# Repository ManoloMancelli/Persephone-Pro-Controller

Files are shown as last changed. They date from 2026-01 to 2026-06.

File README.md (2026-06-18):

# Persephone Pro Controller
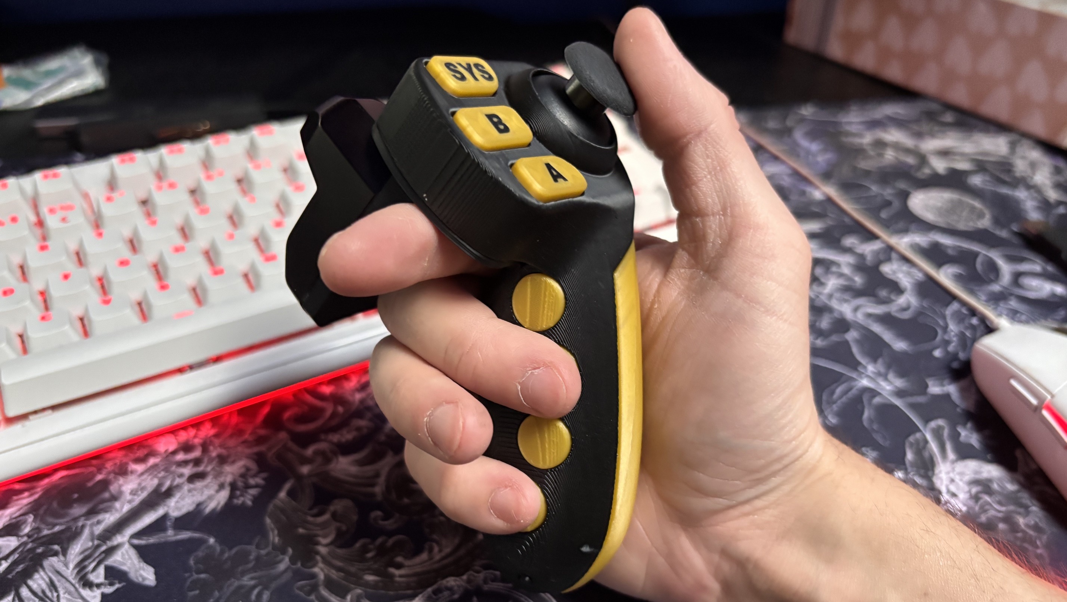
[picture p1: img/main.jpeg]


Persephone Pro controller is a DiY, "knuckle"-like controller for SteamVR

It uses a 3D printed shell and custom electronics based on Arduino along with Vive Tracker for full 6DoF tracking

The controller uses the excellent [HadesVR](https://github.com/HadesVR/HadesVR) Firmware

## V1 - "Clamp" (Finished)

### Known Issues:
- Tracker is oriented in wrong position under SteamVR (Don't know how to fix it yet!)

If orientation is important to you and you can't use it as is, wait for the version 1.1

#

Version 1.0 is meant to function as a "testing rig" for the project.

It's not meant to look pretty and some of the parts may feel uncomfortable.

It's a simple build that will show you how everything works and it's designed to use as cheap parts as possible so if it turns out it's not for you then you won't feel any guilt about it.

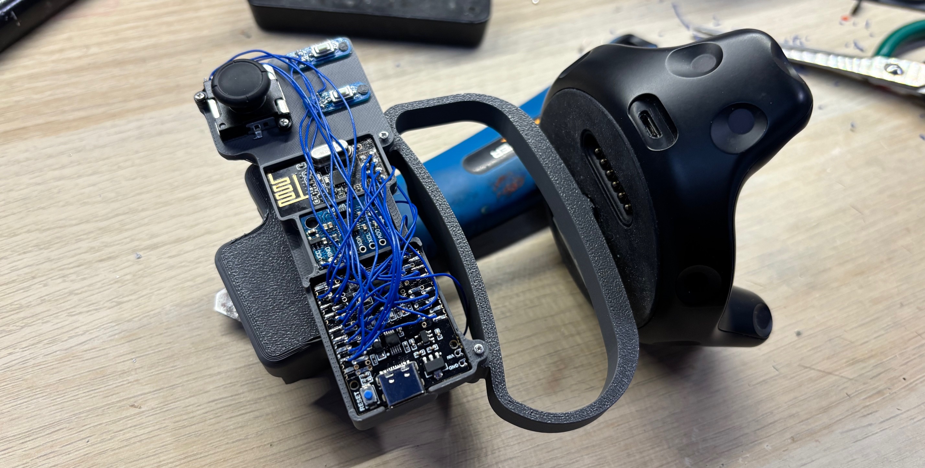
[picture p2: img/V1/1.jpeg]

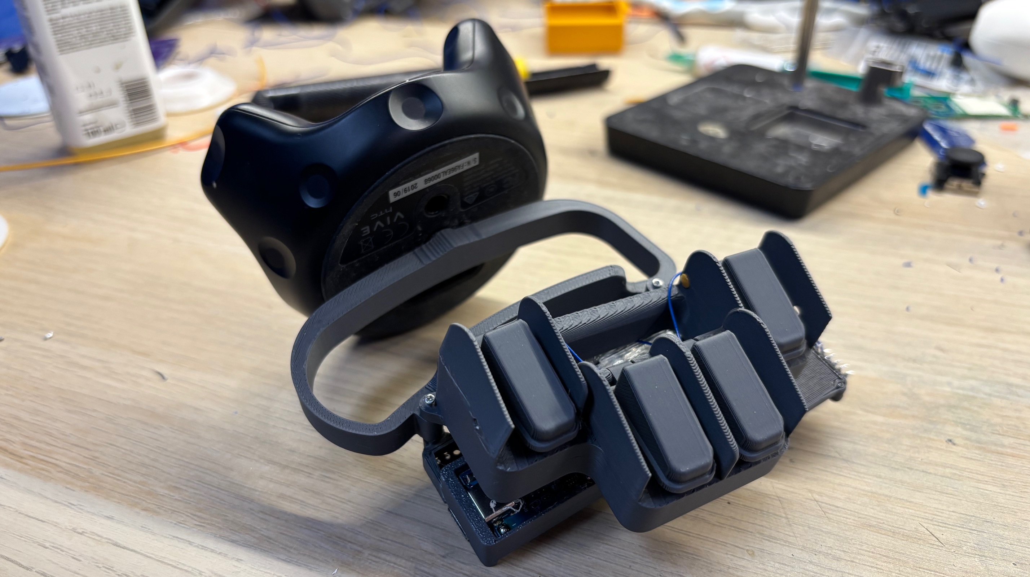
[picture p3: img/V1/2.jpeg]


- #### [Changelog](/Changelog/V1/V1.md)
- #### [Firmware](/Software/Firmware/V1/)
- #### [BOM](/Hardware/V1/BOM.md)
- #### [STL Files](/Hardware/V1/STL)
- #### [CAD Files]()
- #### [Tutorial](/Docs/V1/Tutorial.md)

## V2.0 - "Gas Pump" (Finished)

A Full redesign

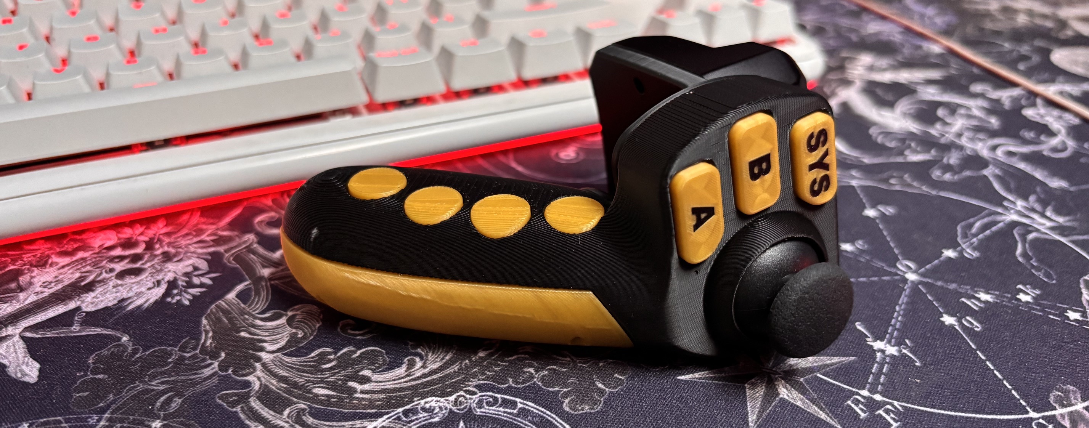
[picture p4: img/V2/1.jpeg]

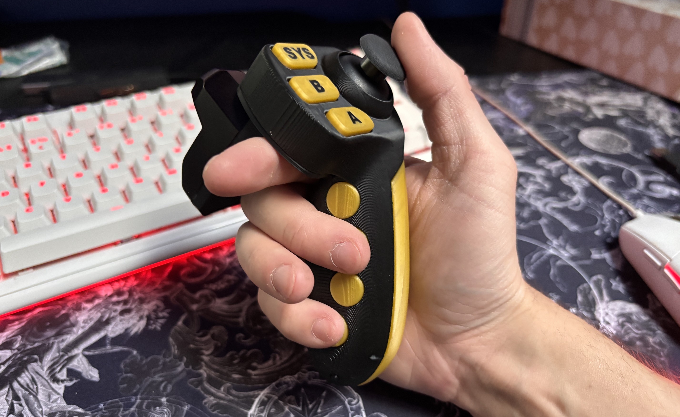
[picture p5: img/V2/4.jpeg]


- #### [Firmware]()
- #### [CAD Files](https://www.patreon.com/Manollo/posts/persephone-pro-0-161451840/)
- #### [STL Files](https://www.patreon.com/Manollo/posts/persephone-pro-0-161452585/)
- #### [HadesVR Index Controller Development Board]()
- #### [Charger Board]()

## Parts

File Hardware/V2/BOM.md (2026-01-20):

# Persephone Pro Controller V2 BOM

Below is a full list of parts and tools required for the V2 version.

Quantities provided are for a single controller

### Components

#### - [10k Potentiometer](https://aliexpress.com/item/1005004816793978.html) - 5 Pcs
#### - [ESP-WROOM-32](https://aliexpress.com/item/1005009709643094.html) - 1 Pcs
#### - Thin wire
#### - 3D printed parts

### Tools

#### - Soldering Iron

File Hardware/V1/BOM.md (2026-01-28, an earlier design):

# Persephone Pro Controller V1 BOM

A full Bill of Materials for the V1 version of Persephone Pro Controller

Below list of parts is for a single controller

- #### [Arduino Uno Mini - 1pcs](http://aliexpress.com/item/1005009656475222.html)
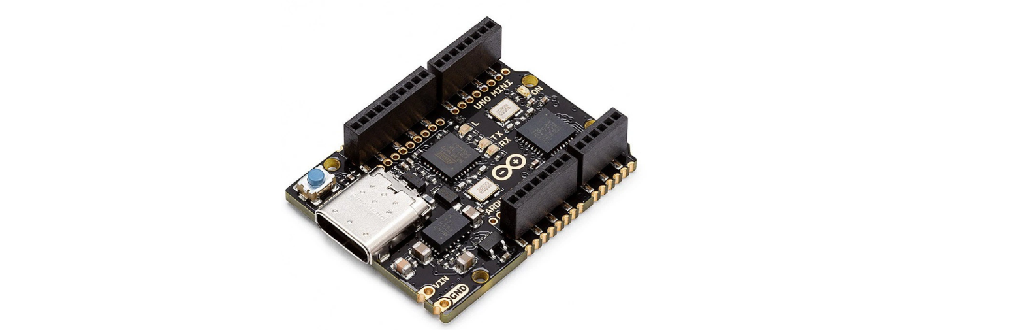
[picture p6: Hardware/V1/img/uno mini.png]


- #### [NRF24L01 - 1pcs](http://aliexpress.com/item/1005001580632657.html)
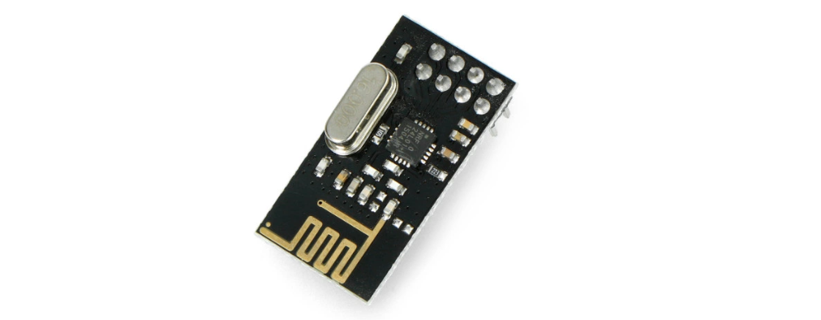
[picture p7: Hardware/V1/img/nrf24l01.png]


- #### [MPU6500 - 1pcs](http://aliexpress.com/item/1005009877371293.html)
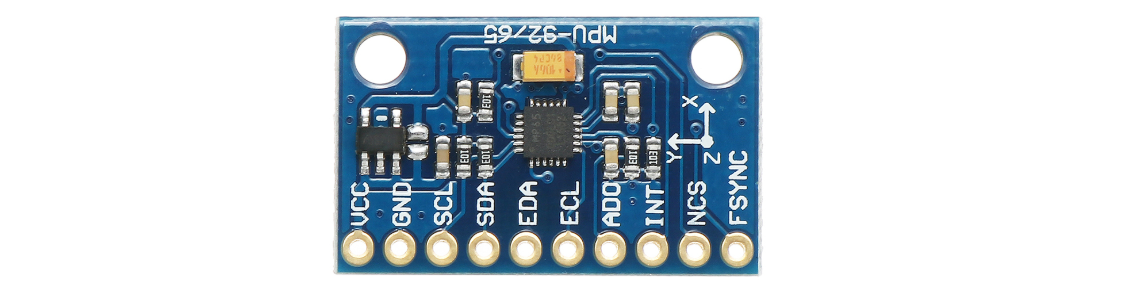
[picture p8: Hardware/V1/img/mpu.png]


- #### [TP4056 - 1pcs](http://aliexpress.com/item/1005009519806288.html)
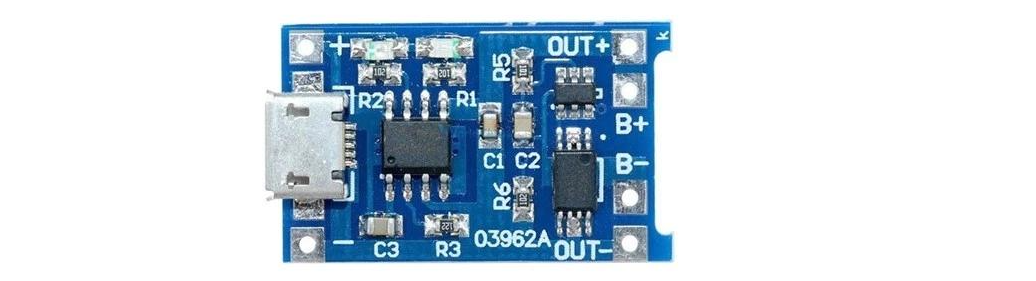
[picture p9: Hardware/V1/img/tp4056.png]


- #### [Battery 3.7V 20x30mm - 1pcs](http://aliexpress.com/item/1005003495504020.html)
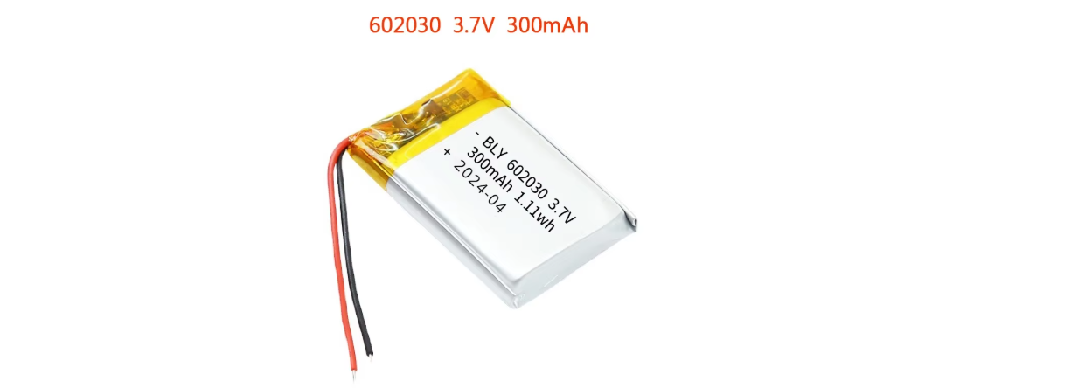
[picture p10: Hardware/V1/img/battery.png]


- #### [Joystick - 1pcs](http://aliexpress.com/item/1005006007198466.html)
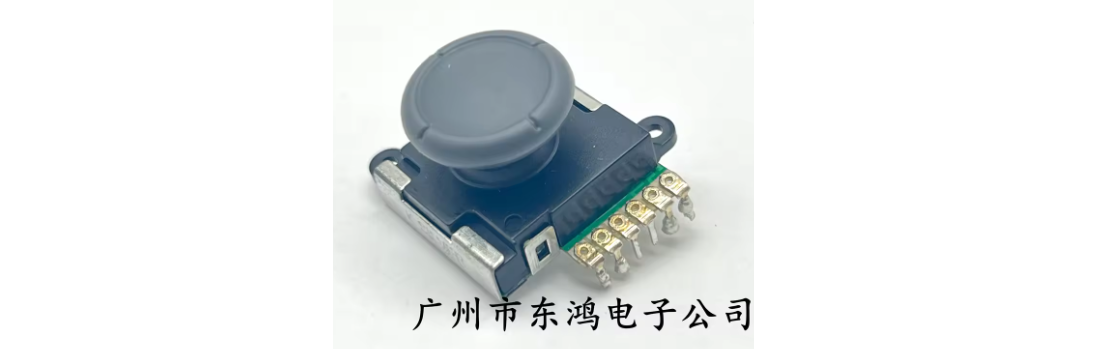
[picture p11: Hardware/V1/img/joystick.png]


- #### [Buttons - 6pcs](http://aliexpress.com/item/1005001836287232.html)
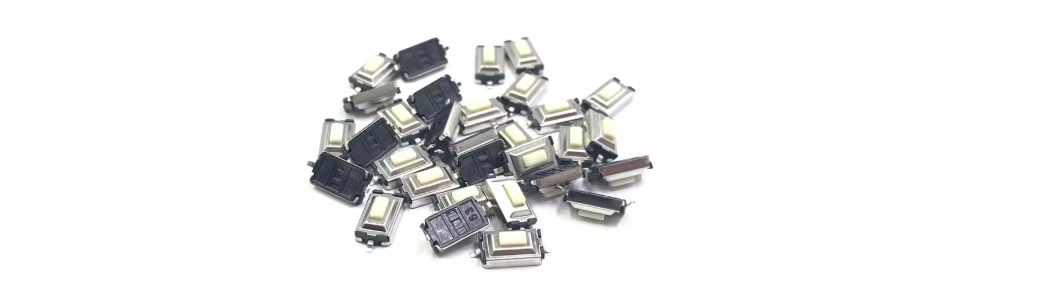
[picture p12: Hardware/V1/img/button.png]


- #### [Button PCB - 6pcs](/Hardware/V1/Electronics/Button%20PCB/Button%20PCB.zip)
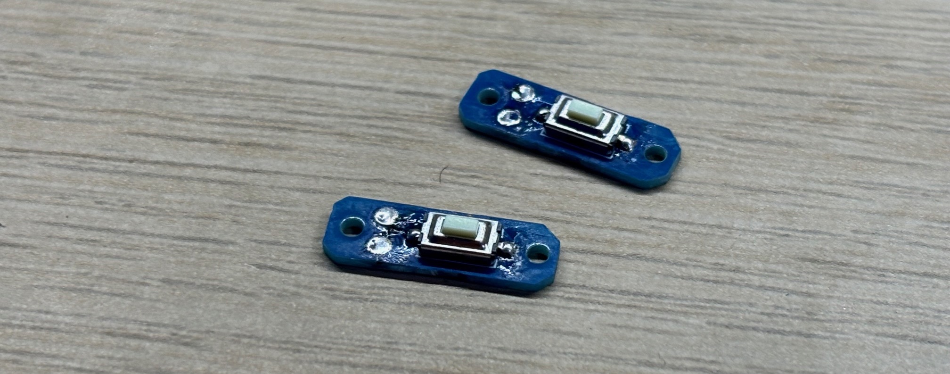
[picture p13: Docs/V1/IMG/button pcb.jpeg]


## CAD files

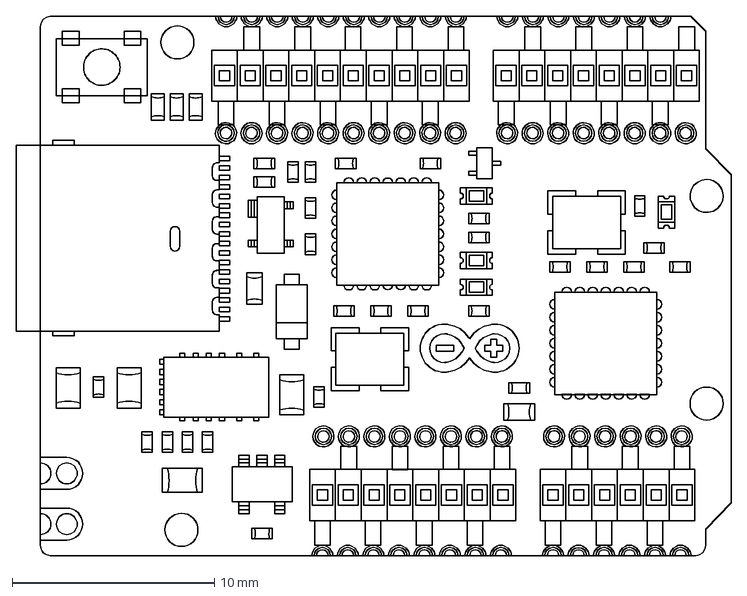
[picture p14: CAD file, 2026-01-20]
Hardware/Arduino Uno Mini.dxf
35.4 x 26.7 mm

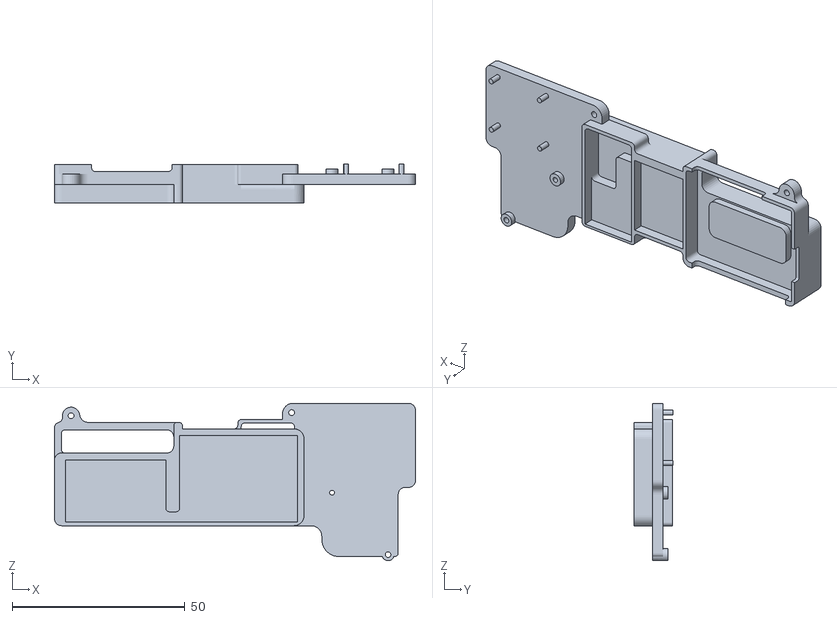
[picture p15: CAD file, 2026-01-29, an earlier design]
Hardware/V1/STL/Main Frame.stl
104.4 x 11.4 x 45.5

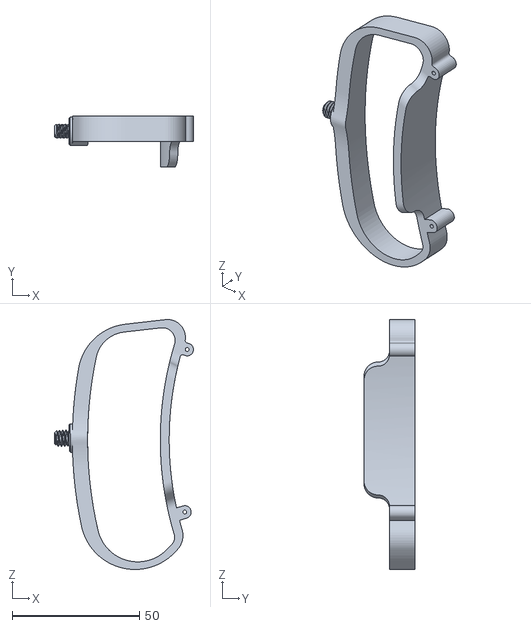
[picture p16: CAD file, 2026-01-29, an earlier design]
Hardware/V1/STL/Bumper.stl
54.6 x 20.0 x 98.1

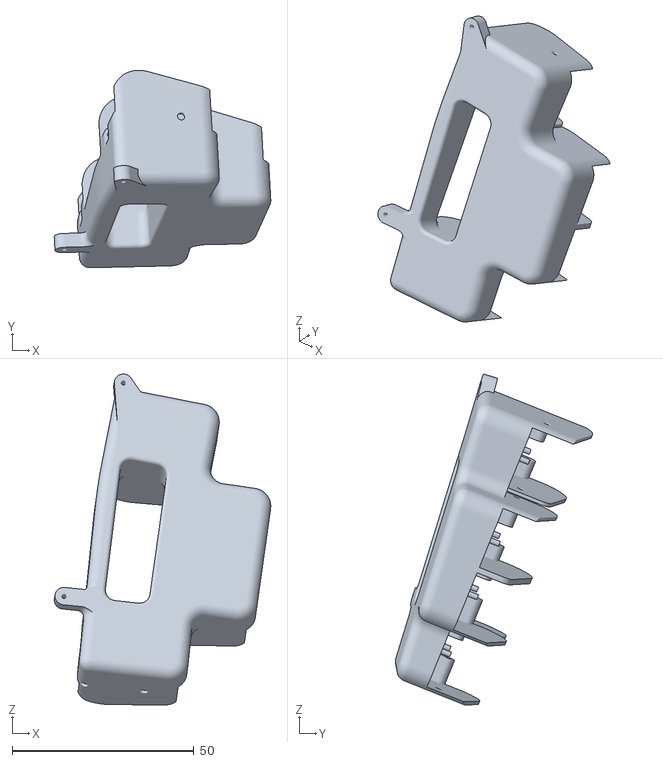
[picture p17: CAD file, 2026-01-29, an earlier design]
Hardware/V1/STL/Finger Array.stl
59.6 x 54.4 x 91.1

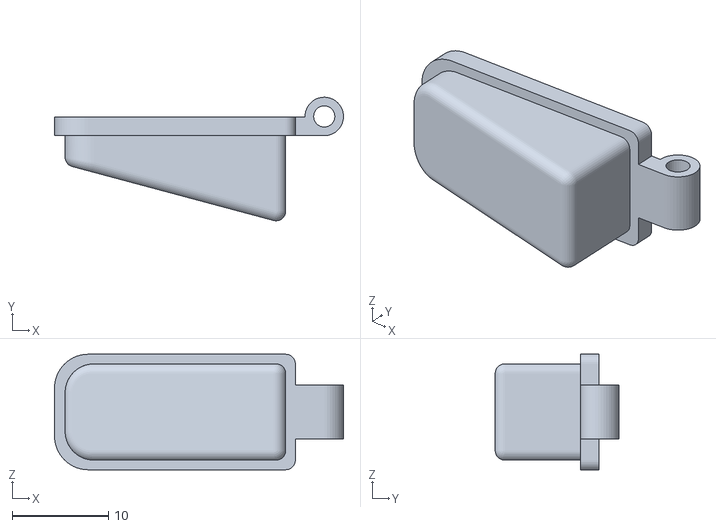
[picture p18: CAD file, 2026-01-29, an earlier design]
Hardware/V1/STL/Finger Button.stl
30.0 x 12.8 x 12.0

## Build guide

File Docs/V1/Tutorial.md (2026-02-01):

# Persephone Pro Controller V1 Assembly Guide

#
## This tutorial assumes that you already have a working HadesVR headset
#

## Required Parts and Tools

#### - All of the electronic parts included in the [BOM File](/Hardware/V1/BOM.md)
#### - Soldering Iron with fine tip
#### - Phillips Screwdriver
#### - Thin wire (I use Kynar)
#### - Double sided tape (Basic type. Nothing fancy)
#### - [3D printed parts](/Hardware/V1/STL)

## Main Frame Assembly

- ### 3D print the [Main Frame](/Hardware/V1/STL/Main%20Frame.stl)
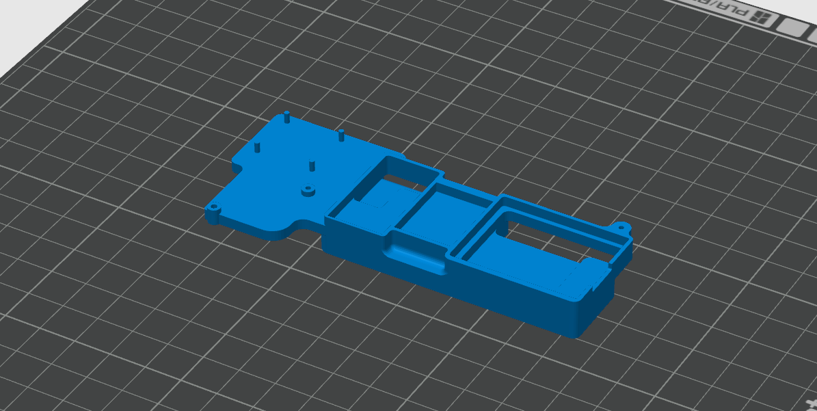
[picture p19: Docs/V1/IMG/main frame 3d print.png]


- ### Assemble the [Button PCBs - 2pcs](/Hardware/V1/Electronics/Button%20PCB/Button%20PCB.zip)


- ### Cut off the battery connector if it comes with one
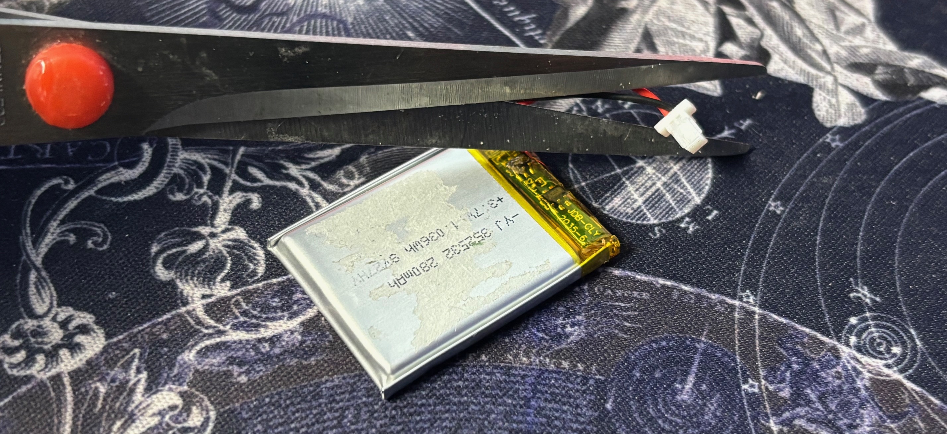
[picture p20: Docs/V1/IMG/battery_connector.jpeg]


- ### Solder the battery to the TP4056 PCB
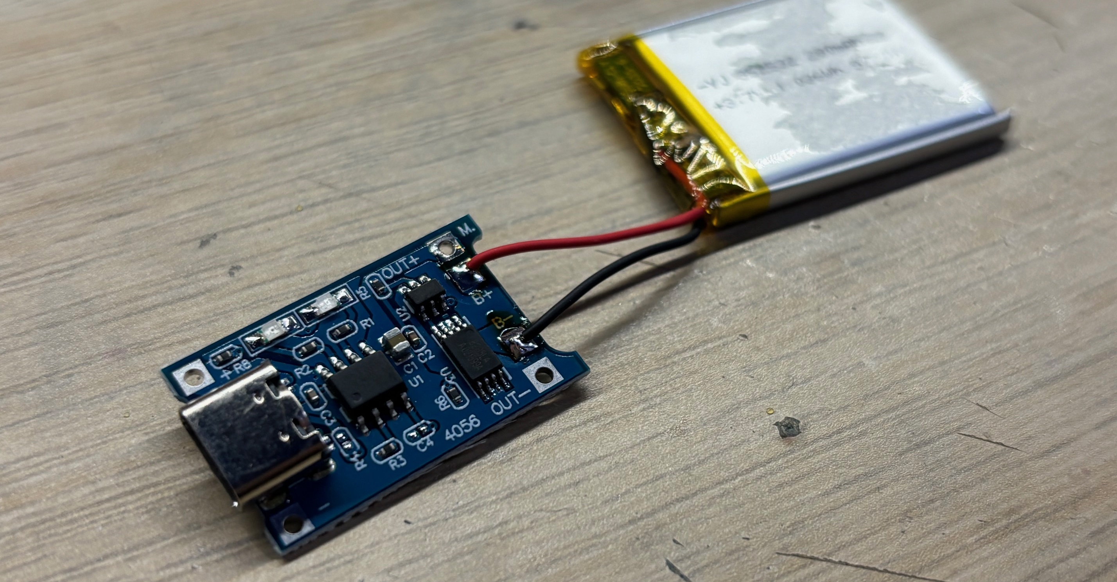
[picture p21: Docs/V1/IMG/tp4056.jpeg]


- ### Apply small ammount of double sided tape to TP4056 and Battery
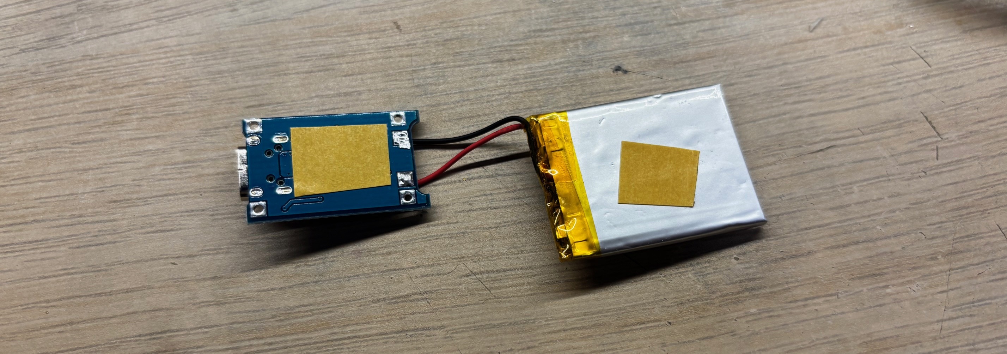
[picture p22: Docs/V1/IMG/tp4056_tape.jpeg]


- ### Stick the TP4056 and Battery into the Main Frame
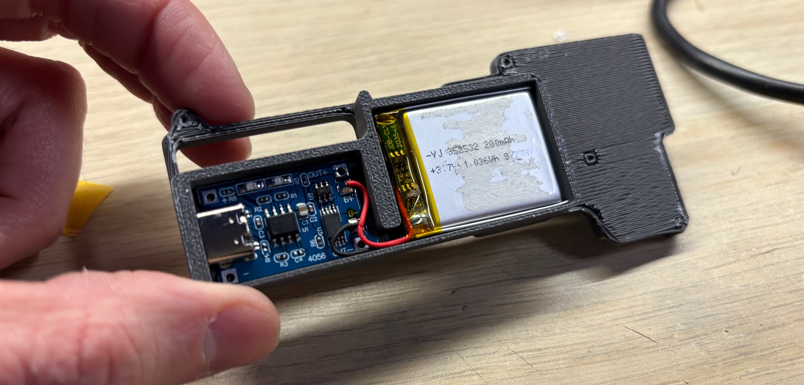
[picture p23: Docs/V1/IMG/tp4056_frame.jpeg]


- ### Apply small ammount of double sided tape to Uno Mini, MPU-6500 and NRF24L01
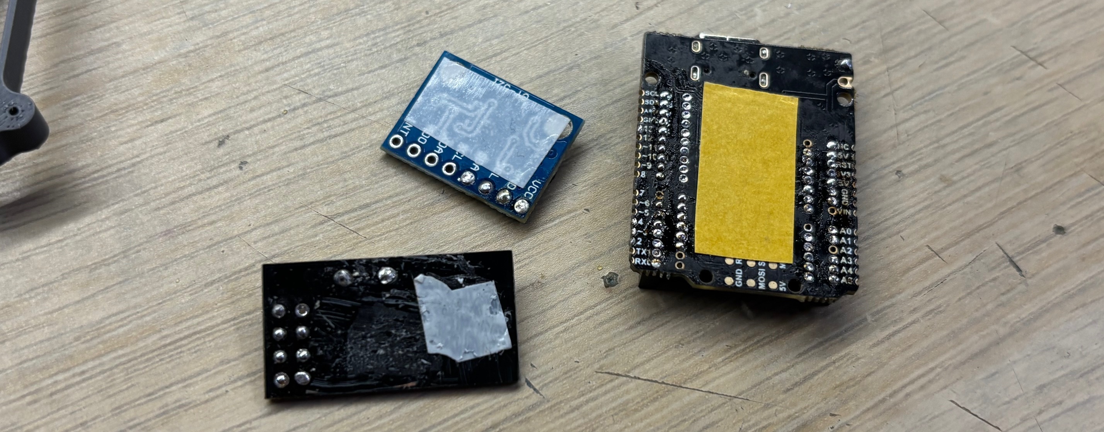
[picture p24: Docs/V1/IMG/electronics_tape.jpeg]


- ### Stick the Uno Mini, MPU-6500 and NRF24L01 into the Main Frame
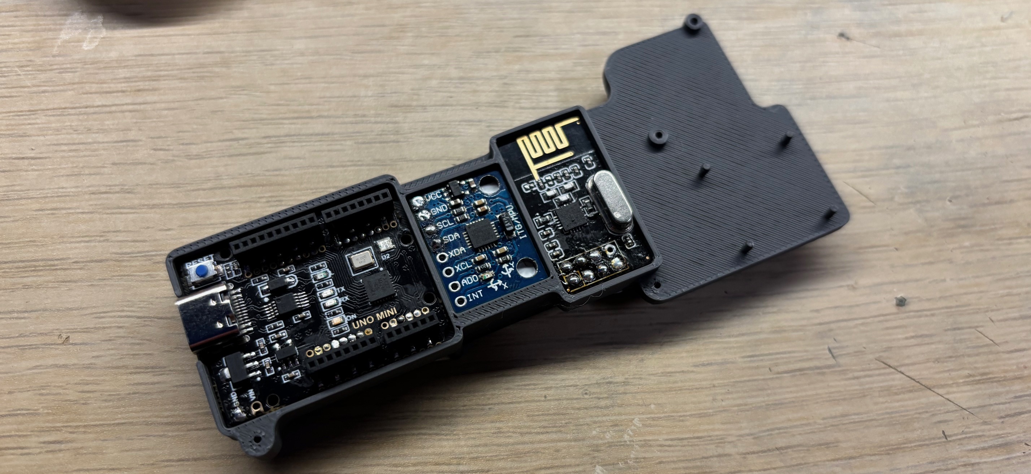
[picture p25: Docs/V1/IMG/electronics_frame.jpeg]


- ### Grab the Button PCBs and stick them over the plastic pillars
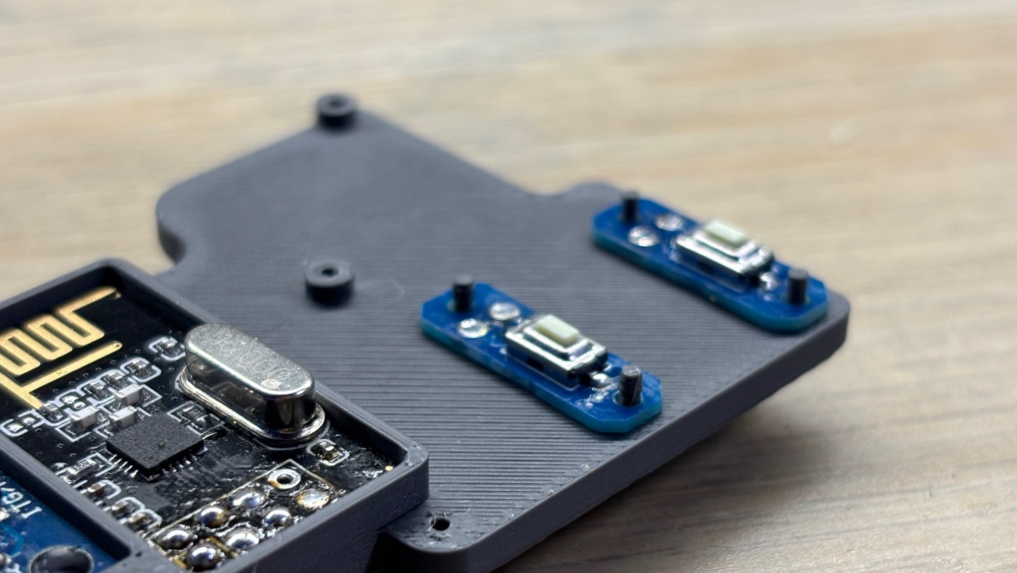
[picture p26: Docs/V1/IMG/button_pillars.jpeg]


- ### Melt the plastic pillars with your soldering iron
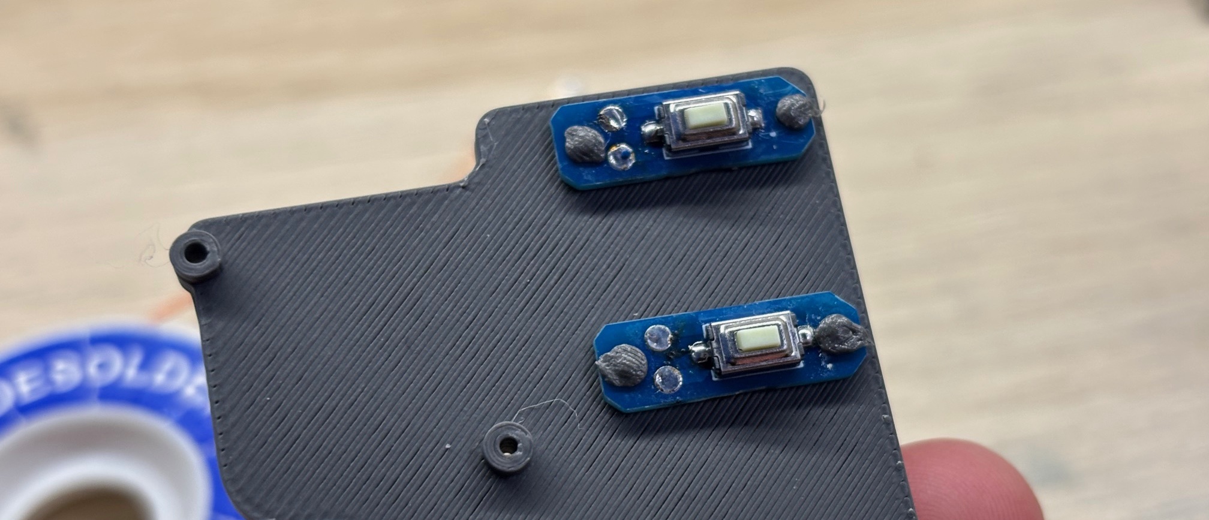
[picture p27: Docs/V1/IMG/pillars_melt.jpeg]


- ### Assemble the Joystick on top of the frame using self tapping screws
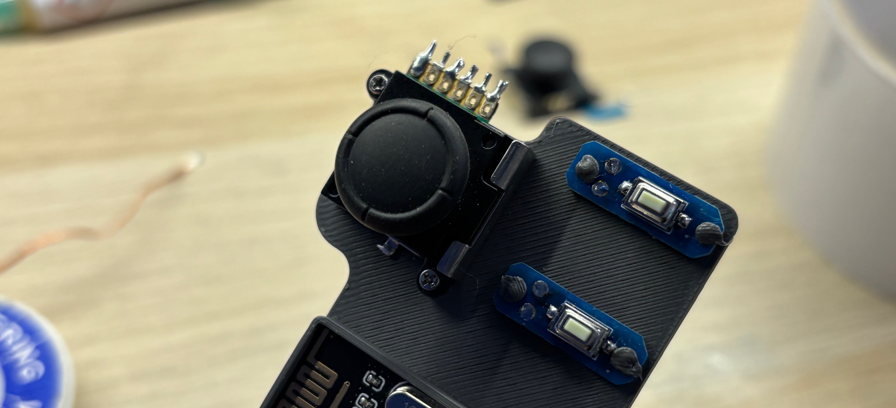
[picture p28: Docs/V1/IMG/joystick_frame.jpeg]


- ### Wire the MPU-6500
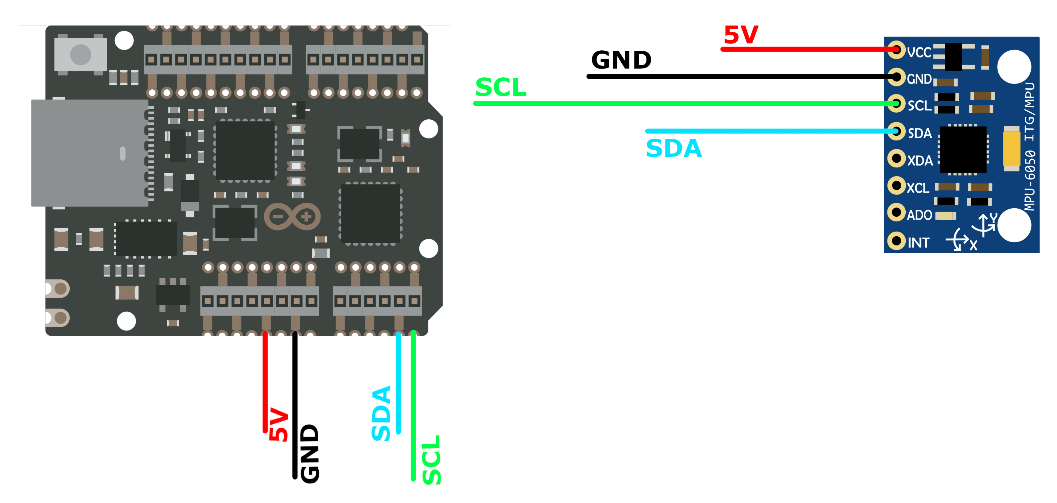
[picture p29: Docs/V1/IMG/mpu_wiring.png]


- ### Wire the NRF24L01
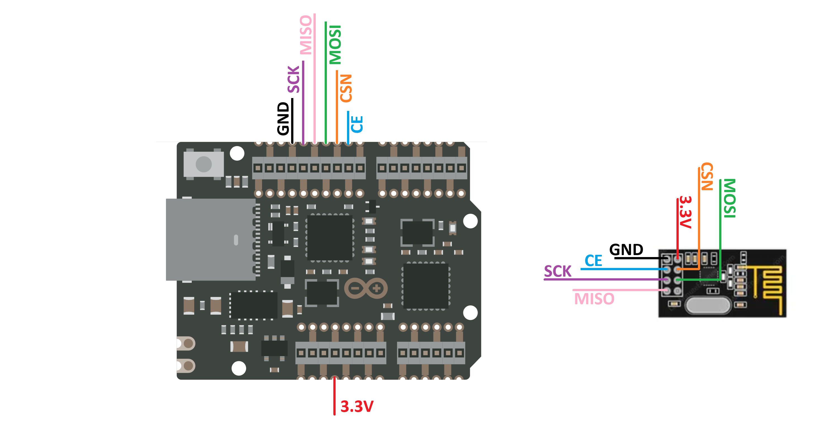
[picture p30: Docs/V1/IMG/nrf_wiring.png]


- ### Wire the Battery and TP4056
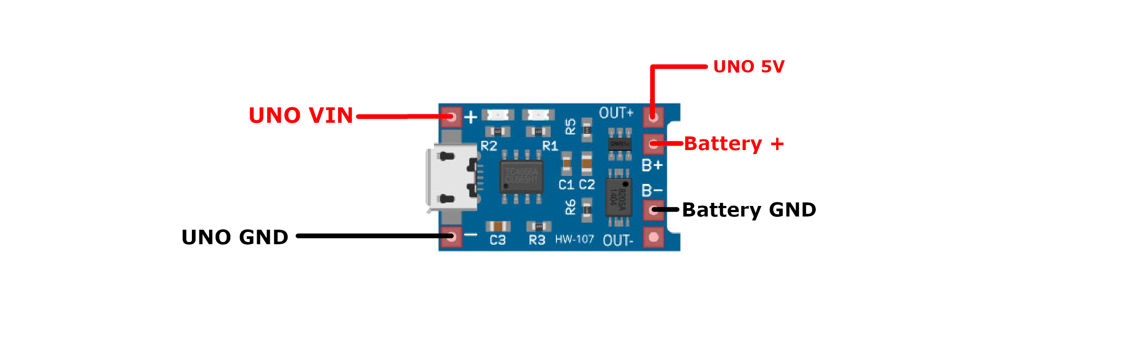
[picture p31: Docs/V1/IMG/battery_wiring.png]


- ### Wire the Joystick
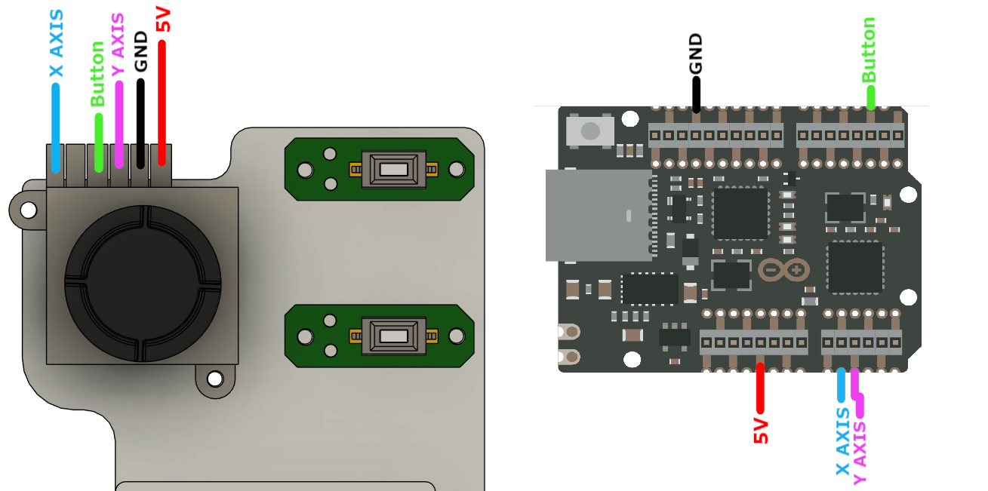
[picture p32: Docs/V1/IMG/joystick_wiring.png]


- ### Wire the A/B Buttons
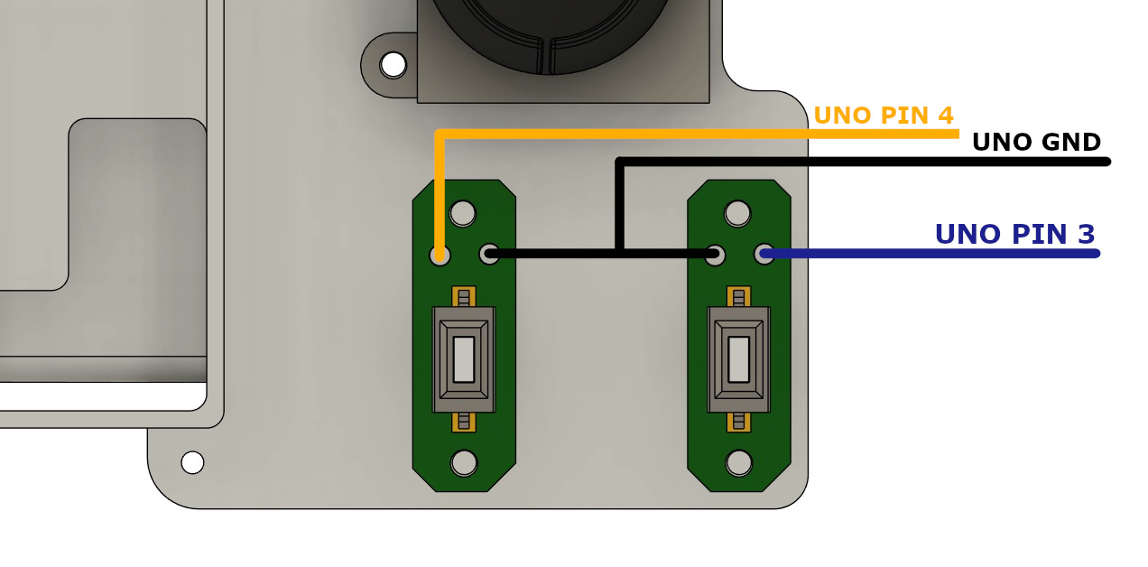
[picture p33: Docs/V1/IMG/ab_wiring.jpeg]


- ### It should now look more or less like this 
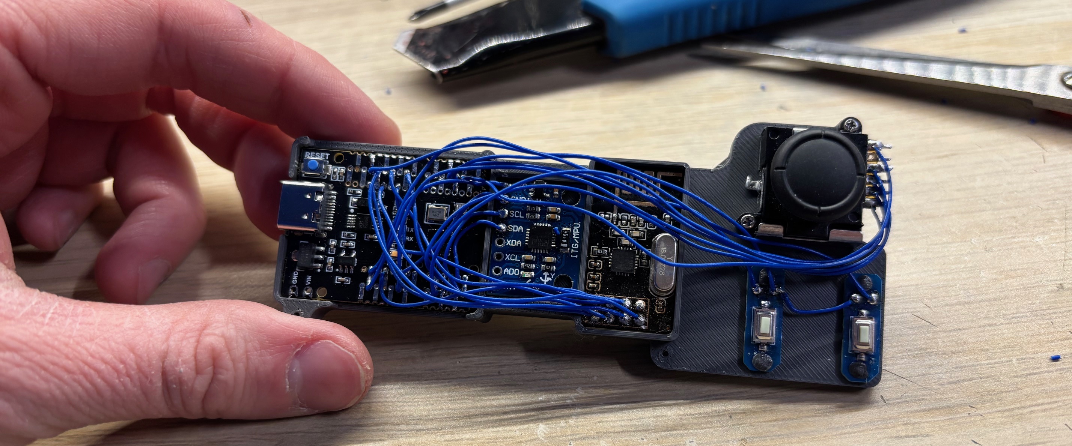
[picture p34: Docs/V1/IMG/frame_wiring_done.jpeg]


## Bumper Assembly
- ### 3D print the [Bumper](/Hardware/V1/STL/Bumper.stl)
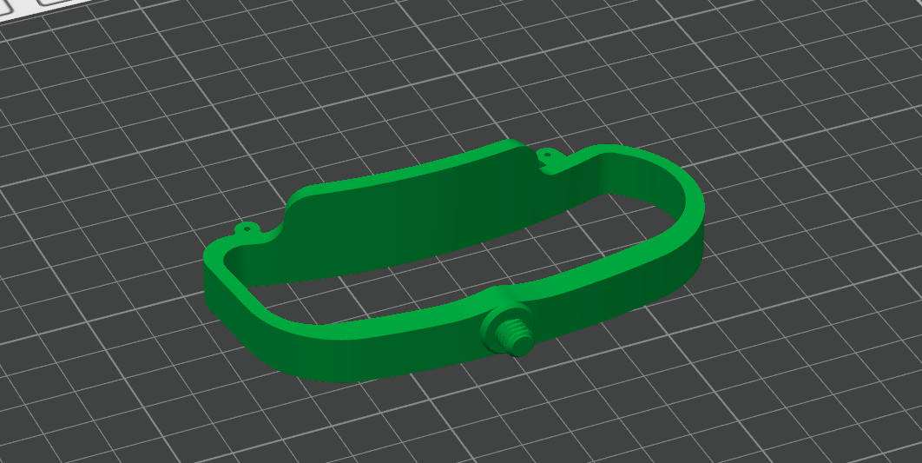
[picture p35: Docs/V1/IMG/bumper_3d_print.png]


- ### Attach the Bumper to the Main Frame using two self-tapping screws
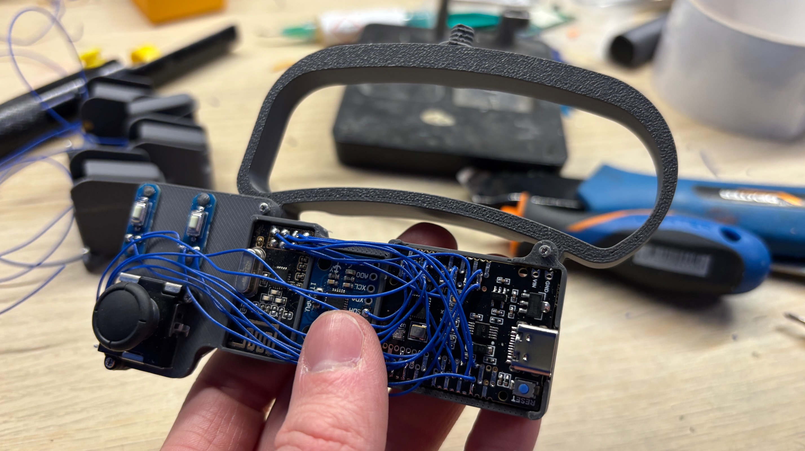
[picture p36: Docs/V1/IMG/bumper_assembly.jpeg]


## Finger Array Assembly

- ### 3D print the [Finger Array]()
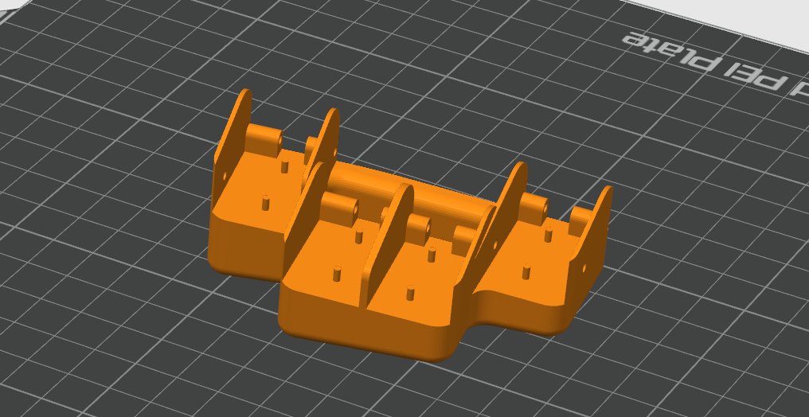
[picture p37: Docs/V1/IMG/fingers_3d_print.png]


- ### 3D print the [Finger Buttons - 4pcs]()
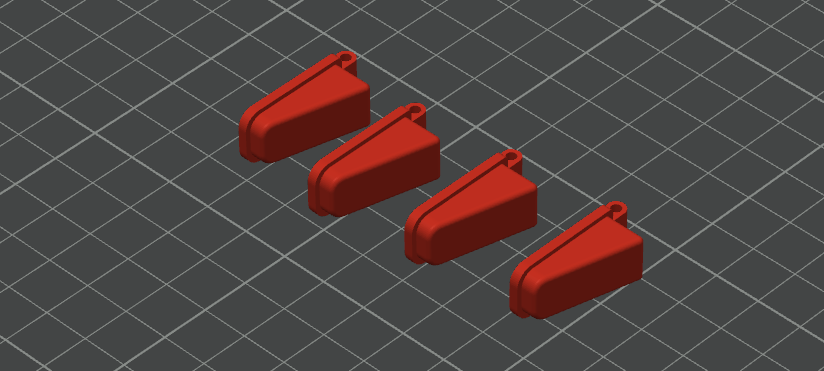
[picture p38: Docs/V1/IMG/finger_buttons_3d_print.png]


- ### Assemble the [Button PCBs - 4pcs](/Hardware/V1/Electronics/Button%20PCB/Button%20PCB.zip)


- ### Place the Button PCBs over the plastic pillars
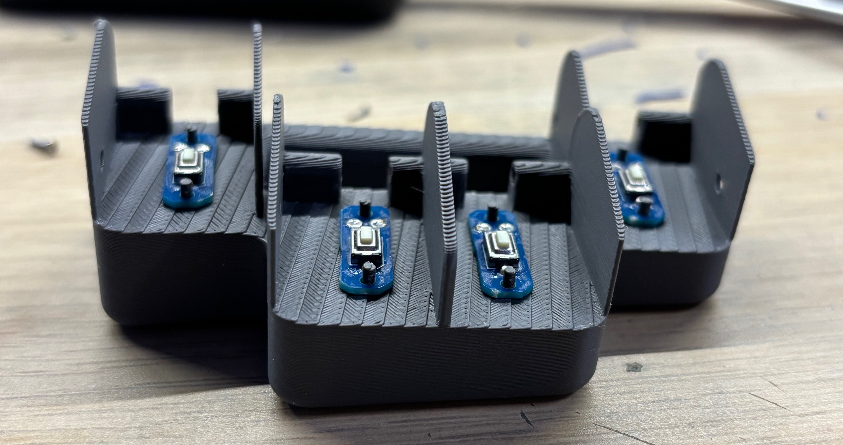
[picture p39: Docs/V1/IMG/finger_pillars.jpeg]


- ### Melt the plastic pillars with your soldering iron
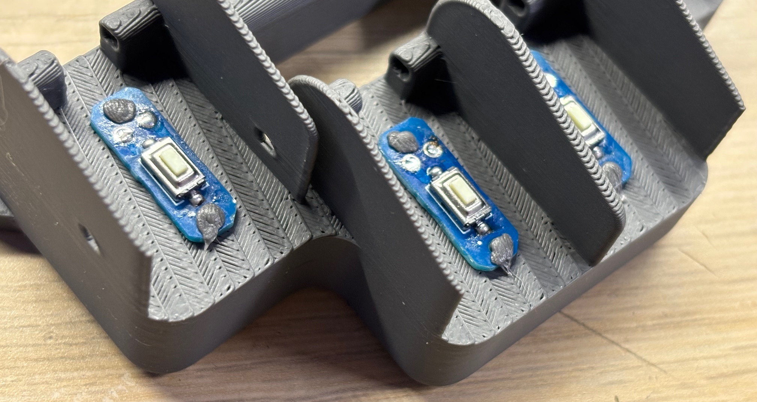
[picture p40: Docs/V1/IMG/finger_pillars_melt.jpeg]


- ### Connect the Finger Array
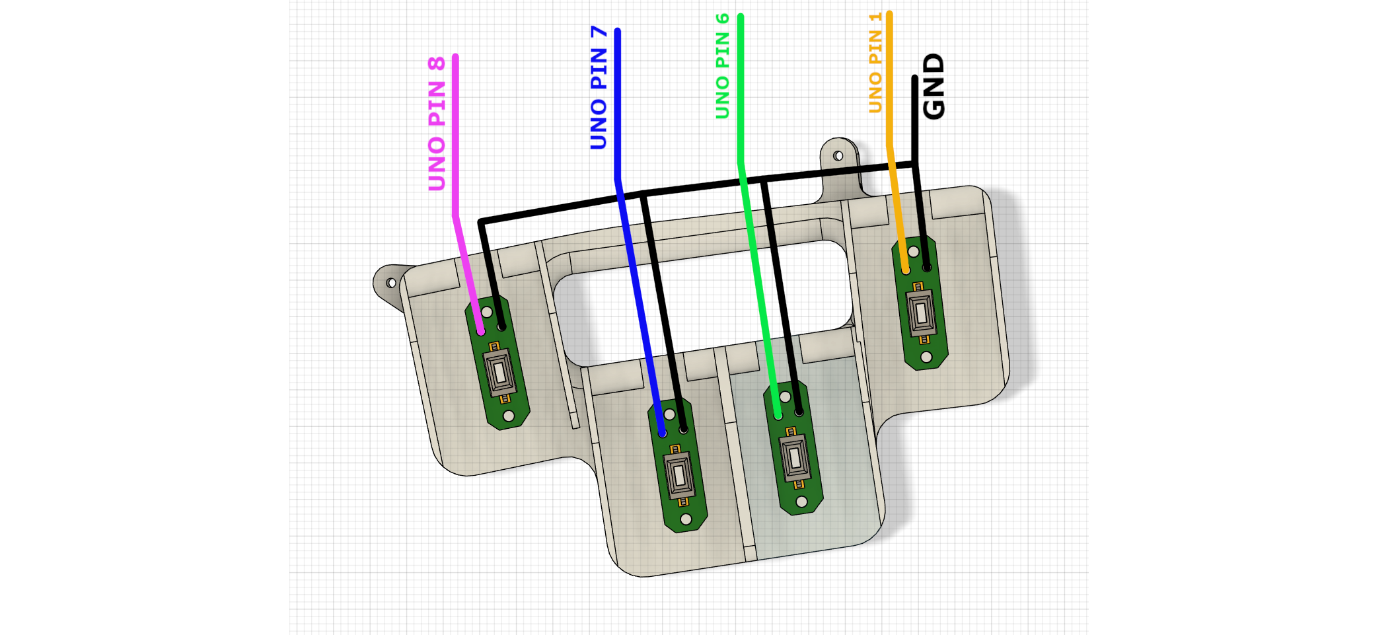
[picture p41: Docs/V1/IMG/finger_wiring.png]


- ### Slide Finger Buttons between the hinge pieces
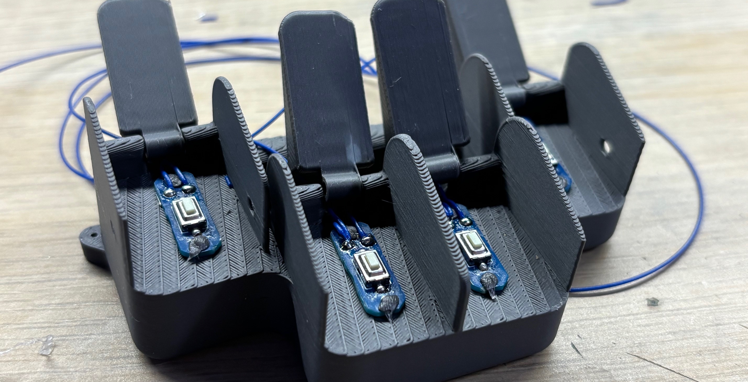
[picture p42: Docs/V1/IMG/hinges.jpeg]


- ### Insert pieces of filament into the hinges
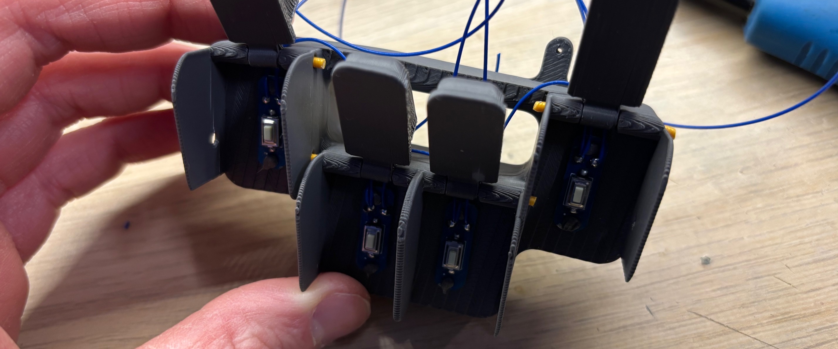
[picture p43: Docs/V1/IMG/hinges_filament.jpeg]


- ### Melt filament ends with your soldering iron
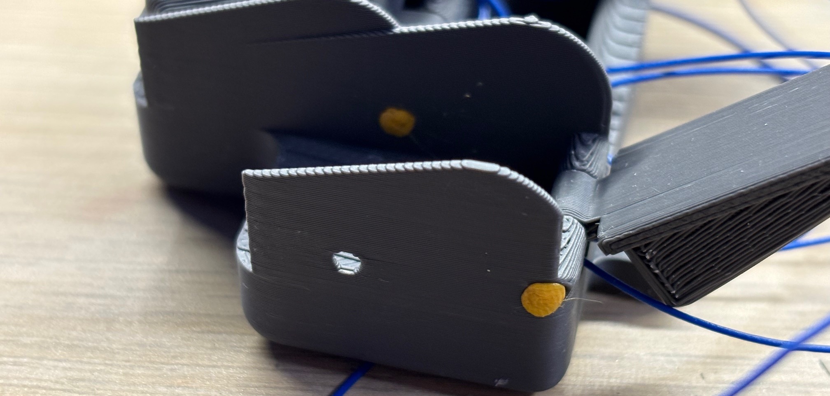
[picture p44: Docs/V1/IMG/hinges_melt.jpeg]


- ### Attach the Finger Array to the Bumper
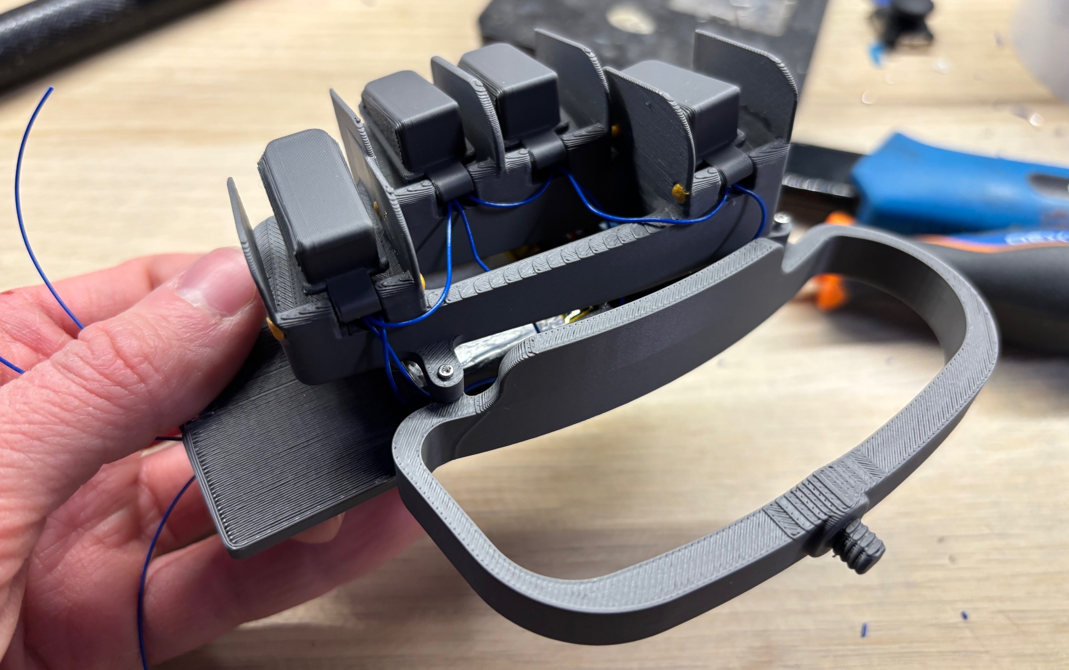
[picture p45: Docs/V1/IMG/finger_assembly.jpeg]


## Vive Tracker installation

- ### Screw the Vive Tracker onto the thread placed on the Bumper
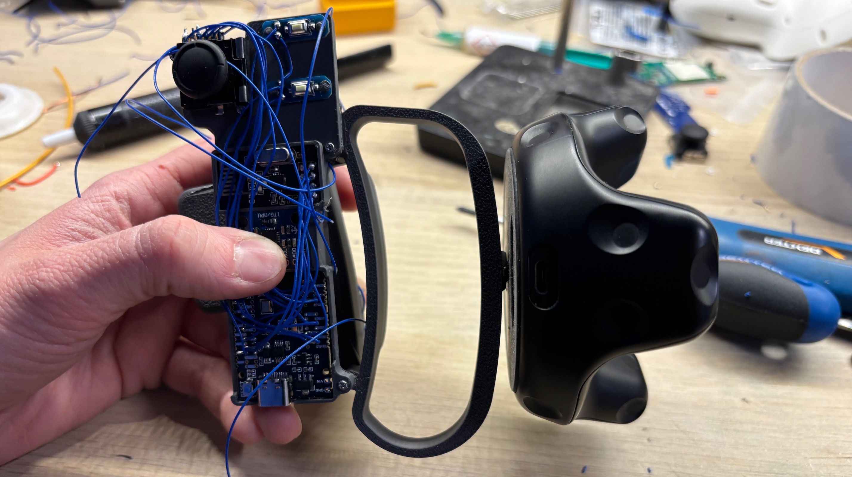
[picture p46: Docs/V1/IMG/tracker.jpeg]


- ### Make sure that the Pogo Pins are in parallel to the Bumper
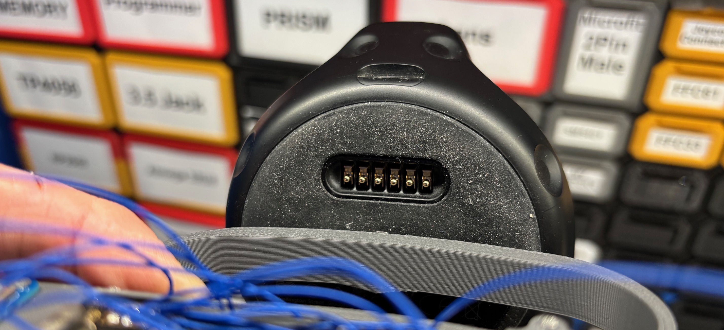
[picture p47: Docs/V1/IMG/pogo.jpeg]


## Firmware Installation

- #### Connect the Controller to your PC using Arduino UNO Mini USB port

- #### Open the [Firmware](/Software/Firmware/V1/Right_Controller) using Arduino IDE

- #### Select correct board and port inside Arduino IDE

#
#
#
#
# Tracking Override

- #### This method is fully working in time of writing this tutorial (SteamVR build 21281713)

## PC Setup
- Install all of the latest Windows updates
- Install Steam Windows App
- Install SteamVR

## SteamVR Setup
- Connect your VR headset and make sure it works properly
- Go trough the Room Setup
- Connect the SteamVR Dongle and pair the tracker
- In SteamVR go to Devices -> Manage Trackers

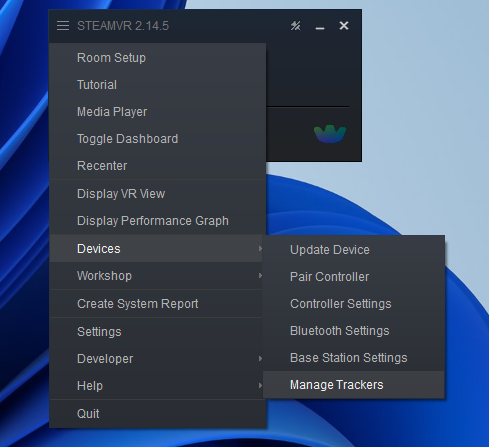
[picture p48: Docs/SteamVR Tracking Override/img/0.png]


- Make sure your tracker has a green dot next to it

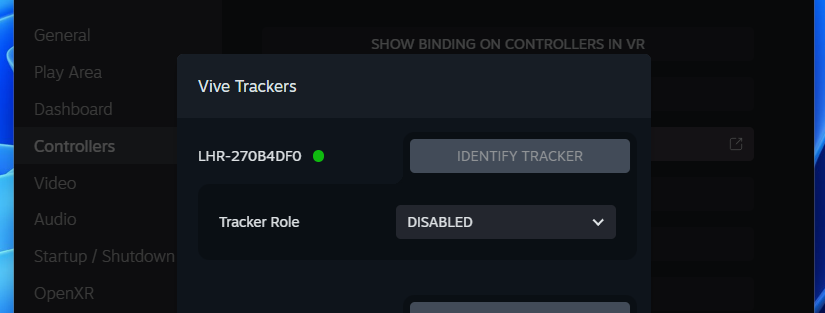
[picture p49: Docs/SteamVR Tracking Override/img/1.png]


- Click on the "Tracker Role" and select "Disabled"

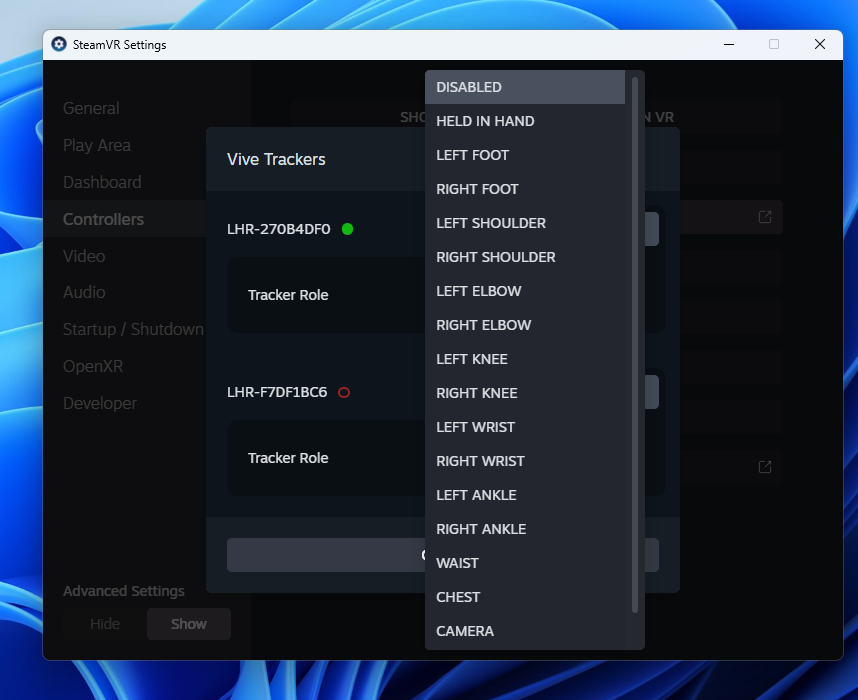
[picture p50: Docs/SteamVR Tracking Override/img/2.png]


- Write down the tracker name



- Close SteamVR if it's running
- Go to C:\Program Files (x86)\Steam\config
- Open steamvr.VRSETTINGS file with text editor (notepad is fine)
- Add below text to the file (make sure to put your tracker name which you've wrote down

```
   "TrackingOverrides" : {
      "/devices/htc/vive_trackerLHR-270B4DF0" : "/user/hand/right"
   },
```

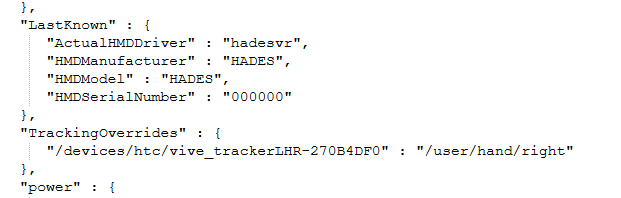
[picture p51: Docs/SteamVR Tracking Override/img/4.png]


- Save the file and close it
- Open SteamVR and enjoy Tracking Override

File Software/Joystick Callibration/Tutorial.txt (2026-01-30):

https://www.instructables.com/Easy-Analog-Joystick-Calibration-and-Centering/

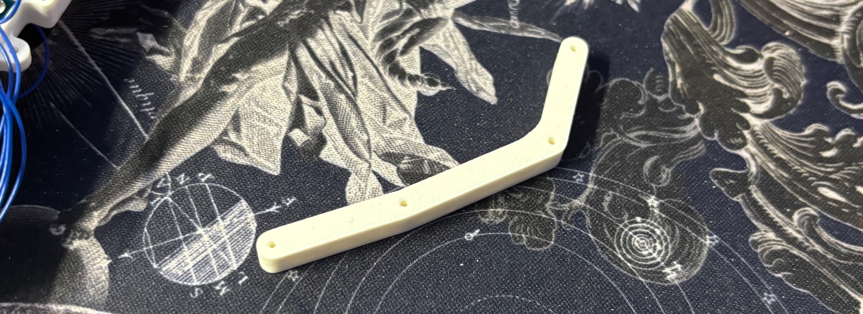
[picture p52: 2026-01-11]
Changelog/V1/img/11.01.2026/assembly1.jpeg

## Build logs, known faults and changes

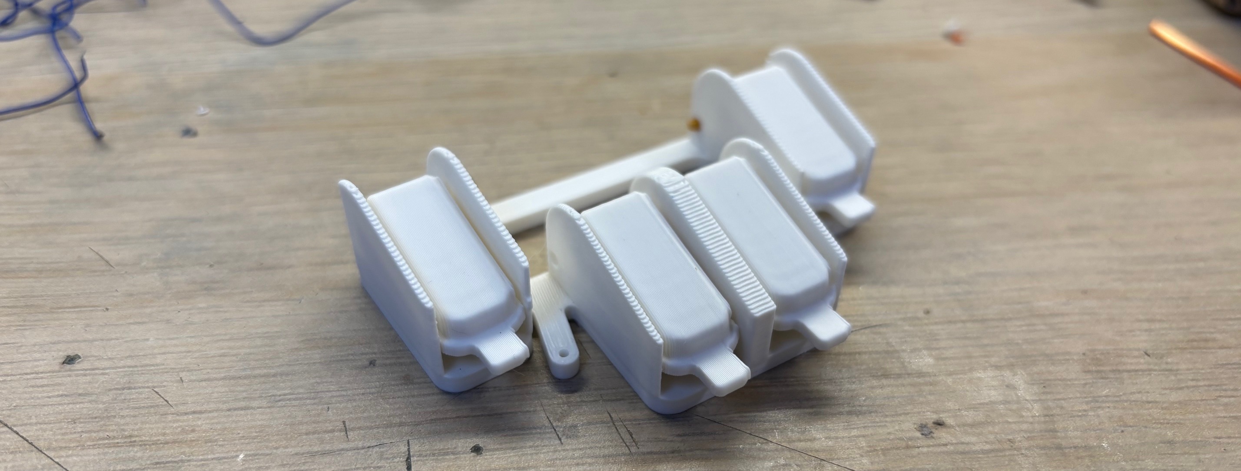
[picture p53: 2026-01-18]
Changelog/V1/img/18.01.2026/fingers3.jpeg

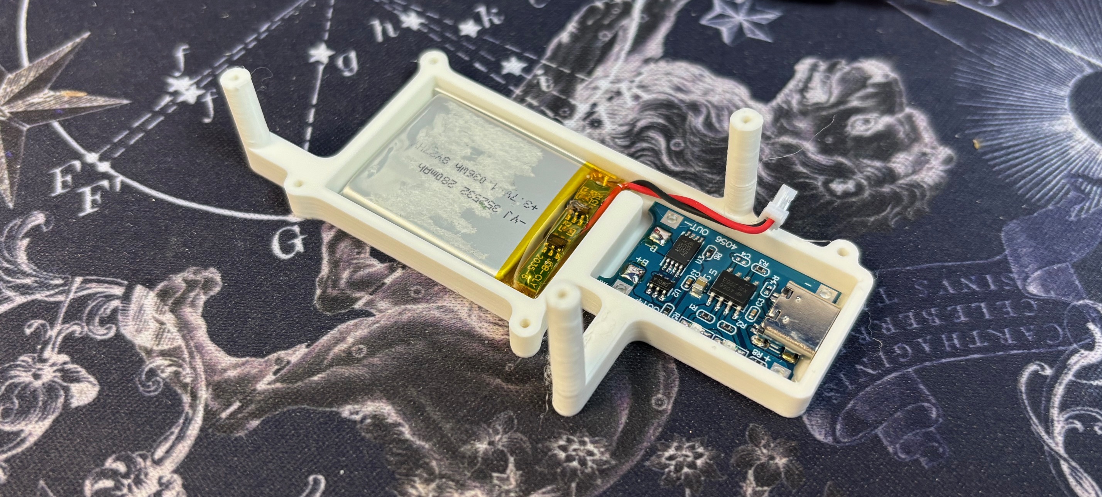
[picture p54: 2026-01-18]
Changelog/V1/img/18.01.2026/battery1.jpeg

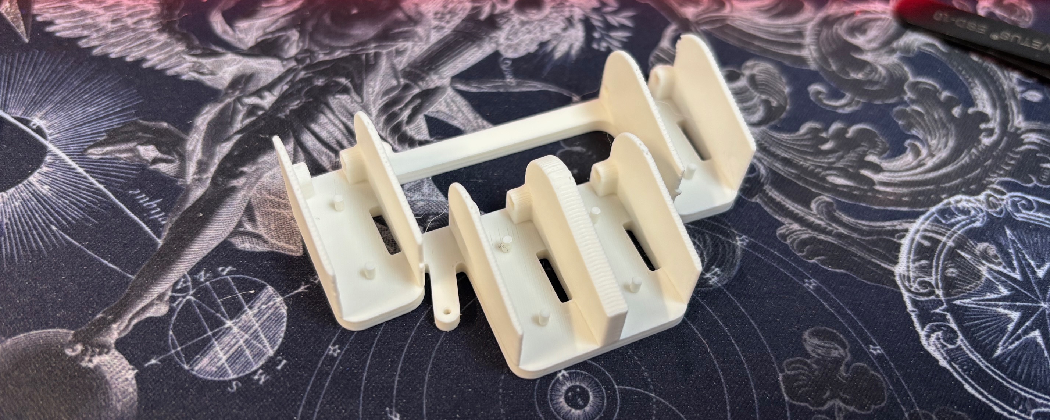
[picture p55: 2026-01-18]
Changelog/V1/img/18.01.2026/fingers2.jpeg

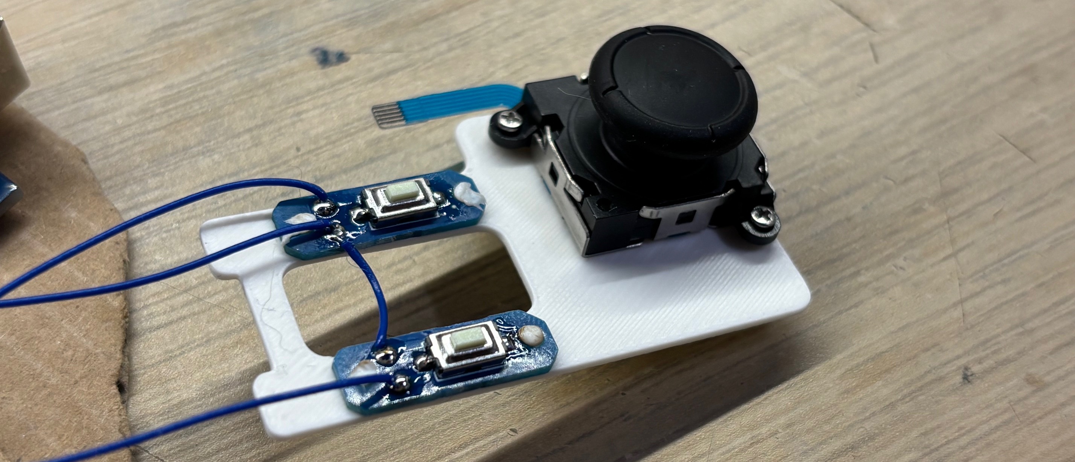
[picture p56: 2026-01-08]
Changelog/V1/img/8.01.2026/joystick1.jpeg

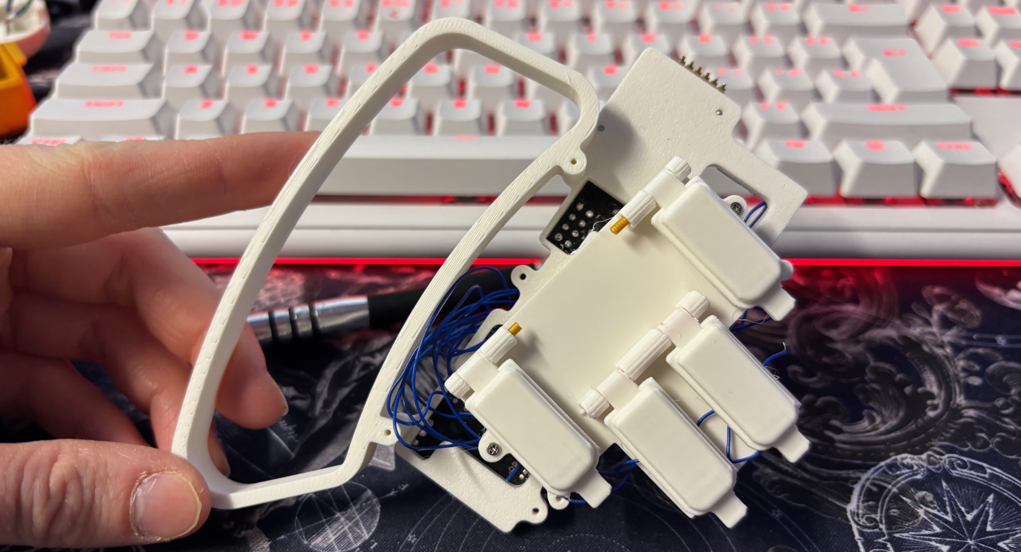
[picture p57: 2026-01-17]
Changelog/V1/img/17.01.2026/fingers1.jpeg

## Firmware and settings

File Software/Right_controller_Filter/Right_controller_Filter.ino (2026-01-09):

/*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
  The above copyright notice and this permission notice shall be included in all copies or substantial portions of the Software.

  THE SOFTWARE IS PROVIDED "AS IS", WITHOUT WARRANTY OF ANY KIND, EXPRESS OR IMPLIED,INCLUDING BUT NOT LIMITED TO
  THE WARRANTIES OF MERCHANTABILITY, FITNESS FOR A PARTICULAR PURPOSE AND NONINFRINGEMENT. IN NO EVENT SHALL THE
  AUTHORS OR COPYRIGHT HOLDERS BE LIABLE FOR ANY CLAIM, DAMAGES OR OTHER LIABILITY, WHETHER IN AN ACTION OF CONTRACT,
  TORT OR OTHERWISE, ARISING FROM, OUT OF OR IN CONNECTION WITH THE SOFTWARE OR THE USE OR OTHER DEALINGS IN THE SOFTWARE.
*/

#include <Wire.h>
#include <SPI.h>
#include <EEPROM.h>
#include "RF24.h"
#include "nRF24L01.h"
#include "FastIMU.h"
#include "Madgwick.h"

//==========================================================================================================
//************************************ USER CONFIGURABLE STUFF HERE*****************************************
//==========================================================================================================

#define SERIAL_DEBUG
#define IMU_ADDRESS     0x68                // You can find it out by using the IMUIdentifier example
MPU6050 IMU;                                // IMU type
#define CALPIN              5              //pin to start mag calibration at power on

#define APin                4
#define BPin                3
#define SysPin              5
#define FingerIndexPin      11
#define FingerMiddlePin     6
#define FingerRingPin       7
#define FingerPinkyPin      8
#define TrackpadPin         A0
#define JoyXPin             A1
#define JoyYPin             A2
#define JoyClickPin         2
#define TriggerPin          A3
#define VbatPin             A6

#define BatLevelMax         968             //you need to find all of these values on your own
#define JoyXMin             237             //check on the utils folder for sketches and instructions
#define JoyXMax             935             //that help on getting these values
#define JoyYMin             190             //YOU NEED TO DO THIS FOR BOTH CONTROLLERS
#define JoyYMax             900             //if you use these values without changing them you MAY
#define JoyXDeadZoneMin     490             //get stick drift
#define JoyXDeadZoneMax     620
#define JoyYDeadZoneMin     420
#define JoyYDeadZoneMax     620
//==========================================================================================================


calData calib =
{ false,                   //data valid?
  {0, 0, 0},              //Accel bias
  {0, 0, 0},              //Gyro bias
  {0, 0, 0},              //Mag bias
  {1, 1, 1},              //Mag Scale
};

#define IB_AClick           0x0001
#define IB_ATouch           0x0002
#define IB_BClick           0x0004
#define IB_BTouch           0x0008
#define IB_SYSClick         0x0010
#define IB_ThumbStickClick  0x0020
#define IB_TrackpadTouch    0x0040
#define IB_ThumbStickTouch  0x0080
//==========================================================================================================
//************************************* Data packet stuff *************************************************
//==========================================================================================================
struct ctrlData {
  int16_t qW;
  int16_t qX;
  int16_t qY;
  int16_t qZ;
  int16_t accX;
  int16_t accY;
  int16_t accZ;
  uint16_t BTN;
  uint8_t  trigg;
  int8_t  axisX;
  int8_t  axisY;
  int8_t  trackY;
  uint8_t  vBAT;
  uint8_t  fingerThumb;
  uint8_t  fingerIndex;
  uint8_t  fingerMiddle;
  uint8_t  fingerRing;
  uint8_t  fingerPinky;
  uint8_t  gripForce;
  uint16_t Data;
};
ctrlData data;
//==========================================================================================================
//**************************************** Analog inputs ***************************************************
//==========================================================================================================
int tracky;
int trackoutput;
int axisX;
int axisY;
bool joyTouch = false;
//==========================================================================================================
//**************************************** RF Data stuff ***************************************************
//==========================================================================================================
RF24 radio(9, 10);
uint64_t Pipe = 0xF0F0F0F0E1LL; //right
//uint64_t Pipe = 0xF0F0F0F0D2LL; //left
//==========================================================================================================
//**************************************** IMU variables ***************************************************
//==========================================================================================================
AccelData IMUAccel;
GyroData IMUGyro;
MagData IMUMag;
//==========================================================================================================
//************************************** Filter variables **************************************************
//==========================================================================================================
Madgwick filter;
static const float MadgwickBeta = 0.16f;
float rot = 0.f;
//==========================================================================================================

void setup() {
  Wire.begin();
  Wire.setClock(400000); //400khz clock

  pinMode(APin, INPUT_PULLUP);
  pinMode(BPin, INPUT_PULLUP);
  pinMode(SysPin, INPUT_PULLUP);
  pinMode(JoyClickPin, INPUT_PULLUP);
  pinMode(TriggerPin, INPUT_PULLUP);
  pinMode(FingerPinkyPin, INPUT_PULLUP);
  pinMode(FingerRingPin, INPUT_PULLUP);
  pinMode(FingerMiddlePin, INPUT_PULLUP);

#ifdef SERIAL_DEBUG
  Serial.begin(9600);
#endif

  radio.begin();
  radio.setPayloadSize(32);
  radio.setPALevel(RF24_PA_MAX);
  radio.setDataRate(RF24_2MBPS);
  radio.openWritingPipe(Pipe);
  radio.startListening();
  radio.setAutoAck(false);

  int err = IMU.init(calib, IMU_ADDRESS);
  if (err != 0)
  {
    Serial.print("IMU ERROR: ");
    Serial.println(err);
    while (true);
  }
  if (!radio.isChipConnected())
  {
    Serial.println("NRF24L01 Module not detected!");
    while (true);
  }
  else
  {
    Serial.println("NRF24L01 Module up and running!");
  }

  EEPROM.get(210, calib);

  bool calDone = !calib.valid;                             //check if calibration values are on flash
  while (calDone)
  {
    delay(1000);
    Serial.print("Calibration not done!");
    if (!digitalRead(CALPIN))
    {
      calDone = false;
    }
  }
  if (!digitalRead(CALPIN)) {
    if (!digitalRead(BPin)) {
      Serial.println("Accelerometer and gyroscope calibration mode.");
      Serial.println("Keep IMU completely still on flat and level surface.");
      delay(8000);
      IMU.calibrateAccelGyro(&calib);
      Serial.println("Accel & Gyro calibration complete!");
      calib.valid = true;
    }
    else {
      if (IMU.hasMagnetometer()) {
        Serial.println("Magnetic calibration mode.");
        Serial.println("Move IMU in figure 8 until done.");
        delay(3000);
        IMU.calibrateMag(&calib);
        Serial.println("Magnetic calibration complete!");
        delay(1000);
      }
    }
    printCalibration();
    Serial.println("Writing values to EEPROM!");
    EEPROM.put(210, calib);
    delay(3000);
  }

  //initialize controller data.
  data.qW = 1;
  data.qX = 0;
  data.qY = 0;
  data.qZ = 0;
  data.BTN = 0;
  data.trigg = 0;
  data.axisX = 0;
  data.axisY = 0;
  data.trackY = 0;
  data.vBAT = 0;
  data.fingerThumb = 0;
  data.fingerIndex = 0;
  data.fingerMiddle = 0;
  data.fingerRing = 0;
  data.fingerPinky = 0;
  data.Data = 0x4B3;

  filter.begin(MadgwickBeta);
  /*
    data.Data |= 0x03;  //non diy index controller identifier
    data.Data |= 0x10;  //controller reports accelerometer values
    data.Data |= 0x20;  //controller does support hand tracking
    //data.Data |= 0x40;  //handtracking type is analog
    data.Data |= 0x80;  //controller color is blue (80 for blue 100 for green 200 for red)
    data.Data |= 0x400; //controller reports battery %
  */
  err = IMU.init(calib, IMU_ADDRESS);
  if (err != 0)
  {
    Serial.print("IMU ERROR: ");
    Serial.println(err);
    while (true);
  }
}

void loop() {

  IMU.update();
  IMU.getAccel(&IMUAccel);
  IMU.getGyro(&IMUGyro);

  if (IMU.hasMagnetometer()) {
    IMU.getMag(&IMUMag);
    filter.update(IMUGyro.gyroX, IMUGyro.gyroY, IMUGyro.gyroZ, IMUAccel.accelX, IMUAccel.accelY, IMUAccel.accelZ, IMUMag.magX, IMUMag.magY, IMUMag.magZ);
  }
  else {
    filter.updateIMU(IMUGyro.gyroX, IMUGyro.gyroY, IMUGyro.gyroZ, IMUAccel.accelX, IMUAccel.accelY, IMUAccel.accelZ);
  }

  rot += (abs(IMUGyro.gyroX) + abs(IMUGyro.gyroY) + abs(IMUGyro.gyroZ));
  if (rot > 64000.f) rot = 64000.f;
  rot *= 0.97f;
  filter.changeBeta(rot * (1.5 - 0.1) / 64000 + 0.1);

  joyTouch = false;
  int btn = 0;
  tracky = analogRead(TrackpadPin);
  if (tracky > 560) {
    trackoutput = 1;
    btn |= IB_TrackpadTouch;
  }
  if (tracky < 300 && tracky > 100) {
    trackoutput = 0;
    btn |= IB_TrackpadTouch;
  }
  if (tracky == 0) {
    trackoutput = -1;
    btn |= IB_TrackpadTouch;
  }
  if (tracky < 550 && tracky > 400) {
    trackoutput = 0;
  }

  axisX = analogRead(JoyXPin);
  axisY = analogRead(JoyYPin);

  if (axisX > JoyXDeadZoneMax || axisX < JoyXDeadZoneMin) {
    if (axisX > JoyXMax) {
      axisX = JoyXMax;
    }
    if (axisX < JoyXMin) {
      axisX = JoyXMin;
    }
    data.axisX = -map(axisX, JoyXMin, JoyXMax, -127, 127);
    btn |= IB_ThumbStickTouch;
    joyTouch = true;
  } else {
    data.axisX = 0;
  }

  if (axisY > JoyYDeadZoneMax || axisY < JoyYDeadZoneMin) {
    if (axisY > JoyYMax) {
      axisY = JoyYMax;
    }
    if (axisY < JoyYMin) {
      axisY = JoyYMin;
    }
    data.axisY = map(axisY, JoyYMin, JoyYMax, -127, 127);
    btn |= IB_ThumbStickTouch;
    joyTouch = true;
  } else {
    data.axisY = 0;
  }


  if (analogRead(TriggerPin) < 1000) {
    data.trigg = map(analogRead(TriggerPin), 1024, 0, 0, 255);
    data.fingerIndex = map(analogRead(TriggerPin), 1024, 0, 0, 255);
  }
  else {
    data.trigg = 0;
    data.fingerIndex = 0;
  }


  if (!digitalRead(APin)) {
    btn |= IB_AClick;
    btn |= IB_ATouch;
  }
  if (!digitalRead(BPin)) {
    btn |= IB_BClick;
    btn |= IB_BTouch;
  }
  if (!digitalRead(SysPin)) {
    btn |= IB_SYSClick;
  }
  if (!digitalRead(JoyClickPin)) {
    btn |= IB_ThumbStickClick;
  }
  //  if (digitalRead(FingerIndexPin)) {
  //    data.fingerIndex = 255;
  //  }
  //  else {
  //    data.fingerIndex = 0;
  //  }
  data.gripForce = 0;
  if (digitalRead(FingerMiddlePin)) {
    data.fingerMiddle = 0;
    data.gripForce += 128;
  }
  else {
    data.fingerMiddle = 255;
  }
  if (digitalRead(FingerRingPin)) {
    data.fingerRing = 0;
     data.gripForce += 64;
  }
  else {
    data.fingerRing = 255;
  }
  if (digitalRead(FingerPinkyPin)) {
    data.fingerPinky = 0;
     data.gripForce += 63;
  }
  else {
    data.fingerPinky = 255;
  }


  data.BTN = btn;
  data.trackY = (trackoutput * 127);
  data.vBAT = (map(analogRead(VbatPin), 787, BatLevelMax, 0, 255));
  data.qW = (int16_t)(filter.getQuatW() * 32767.f);
  data.qX = (int16_t)(filter.getQuatY() * 32767.f);
  data.qY = (int16_t)(filter.getQuatZ() * 32767.f);
  data.qZ = (int16_t)(filter.getQuatX() * 32767.f);
  data.accX = (short)(IMUAccel.accelX * 2048);
  data.accY = (short)(IMUAccel.accelY * 2048);
  data.accZ = (short)(IMUAccel.accelZ * 2048);

  radio.stopListening();
  radio.write(&data, sizeof(ctrlData));
  radio.startListening();

  Serial.print("AX: ");
  Serial.print(IMUAccel.accelX);
  Serial.print(",AY: ");
  Serial.print(IMUAccel.accelY);
  Serial.print(",AZ: ");
  Serial.print(IMUAccel.accelZ);
  Serial.print(",GX: ");
  Serial.print(IMUGyro.gyroX);
  Serial.print(",GY: ");
  Serial.print(IMUGyro.gyroY);
  Serial.print(",GZ: ");
  Serial.println(IMUGyro.gyroZ);
}
void printCalibration()
{
  Serial.println("Accel biases X/Y/Z: ");
  Serial.print(calib.accelBias[0]);
  Serial.print(", ");
  Serial.print(calib.accelBias[1]);
  Serial.print(", ");
  Serial.println(calib.accelBias[2]);
  Serial.println("Gyro biases X/Y/Z: ");
  Serial.print(calib.gyroBias[0]);
  Serial.print(", ");
  Serial.print(calib.gyroBias[1]);
  Serial.print(", ");
  Serial.println(calib.gyroBias[2]);
  if (IMU.hasMagnetometer()) {
    Serial.println("Mag biases X/Y/Z: ");
    Serial.print(calib.magBias[0]);
    Serial.print(", ");
    Serial.print(calib.magBias[1]);
    Serial.print(", ");
    Serial.println(calib.magBias[2]);
    Serial.println("Mag Scale X/Y/Z: ");
    Serial.print(calib.magScale[0]);
    Serial.print(", ");
    Serial.print(calib.magScale[1]);
    Serial.print(", ");
    Serial.println(calib.magScale[2]);
  }
  delay(5000);
}

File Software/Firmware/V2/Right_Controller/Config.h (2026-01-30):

//==========================================================================================================
//************************************ USER CONFIGURABLE STUFF HERE*****************************************
//==========================================================================================================
#define SERIAL_DEBUG
#define CALPIN              5              //pin to start mag calibration at power on
#define APin                4
#define BPin                3
#define SysPin              5
#define FingerIndexPin      1
#define FingerMiddlePin     6
#define FingerRingPin       7
#define FingerPinkyPin      8
#define JoyXPin             A2
#define JoyYPin             A1
#define JoyClickPin         2
#define VbatPin             A6

#define BatLevelMax         968             //you need to find all of these values on your own
#define JoyXMin             212             //check on the utils folder for sketches and instructions
#define JoyXMax             741             //that help on getting these values
#define JoyYMin             261             //YOU NEED TO DO THIS FOR BOTH CONTROLLERS
#define JoyYMax             674             //if you use these values without changing them you MAY
#define JoyXDeadZoneMin     460             //get stick drift
#define JoyXDeadZoneMax     480
#define JoyYDeadZoneMin     460
#define JoyYDeadZoneMax     490
//==========================================================================================================
//**************************************** RF Data stuff ***************************************************
//==========================================================================================================
uint64_t Pipe = 0xF0F0F0F0E1LL; //right
//uint64_t Pipe = 0xF0F0F0F0D2LL; //left

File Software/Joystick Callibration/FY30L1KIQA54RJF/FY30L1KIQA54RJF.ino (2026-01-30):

//  **********************************************************************//
//  author: Joram de Poel                                                 //
//  date:   8-7-2016                                                      //
//  version: 1.3                                                          //
//  email: joramdepoel@gmail.com                                          //
//  **********************************************************************//
//
//  This code is free to use, edit and distrubate as long as you use it for non profit projects
//
//  this code is writen to use analog joysticks in the easiest way possible and with the most options
//  this code deals with ofsets, limited range, inverted axis and many other problems with joysticks
//  this code uses the map_float function, if you didnt already include this in your arduino core, 
//  just uncomment the function at the bottom

//*****************define your pins here***********************************************//
#define joystick_X A1    //joystick  X-as
#define joystick_Y A2    //joystick  Y-as
#define button_2 2       // button pin


//****************define the min, max and center you want for your joystick here*******//
long range_X_min = 1000;           //lowest X value
long range_X_max = 10000;          //highest X value
long range_X_center = 0;           //X center calue
unsigned long deadZone_X = 1;      //deadzone X, return center value for center +- deadzone(in steps of 1/1024)

float range_Y_min = 0;             //lowest Y value
float range_Y_max = 1023;          //highest Y value
float range_Y_center = 512;        //Y center value
unsigned long deadZone_Y = 1;      //deadzone Y, return center value for center +- deadzone(in steps of 1/1024)


//***************calibration variables************************************************//
int val_X, val_Y;

unsigned long X_CENTER, X_MIN, X_MAX;
unsigned long Y_CENTER, Y_MIN, Y_MAX;

unsigned long cal_X;
unsigned long cal_Y;


//************setup******************************************************************//

void setup() {
  Serial.begin(9600);
  pinMode(joystick_X, INPUT);
  pinMode(joystick_Y, INPUT);
  pinMode(button_2, INPUT_PULLUP);    //we pull this pin high to avoid a floating pin
  calibrate();
}

long joy_X(long X) {
  X += (X_CENTER-512);   //should always be 512
  if (X <= 512) {
    X = mapfloat(X, X_MIN, X_CENTER, range_X_min, range_X_center);   //min,center to range min, range center
    return X;
  }
  else if (X > 512) {
    X = mapfloat(X, 512, 1024 + X_CENTER, range_X_center, range_X_max);
    return X;
  }
}

long joy_Y(long Y) {
  Y += (Y_CENTER-512);
  if (Y <= range_Y_center) {
    Y = mapfloat(Y, Y_CENTER, 512, 0, 512);
    return Y;
  }
  else if (Y > range_Y_center) {
    Y = mapfloat(Y, 512, 1024 + Y_CENTER, 512, 1024);
    return Y;
  }
}

void loop() {
  val_X = analogRead(joystick_X);
  Serial.print(joy_X(val_X)); Serial.print(" : ");
  delay(50);
  val_Y = analogRead(joystick_Y);
  Serial.println(joy_Y(val_Y));
  delay(50);
  if (digitalRead(button_2) == LOW) {
    calibrate();    //you can call any function you want here, this is just to show the possibilities
  }
}

void set_range_X(float min, float max, float center) {
  range_X_min = min;
  range_X_max = max;
  range_X_center = center;
}

void set_range_Y(float min, float max, float center) {
  range_Y_min = min;
  range_Y_max = max;
  range_Y_center = center;
}

void calibrate() {
  Serial.println("\n---calibrating joystick---\n");
  Serial.println("place the joystick in the center position");
  cal_X = 0;
  cal_Y = 0;
  delay(5000);
  Serial.print("calibrating center");
  for (int i = 0; i < 100; i++) {
    Serial.print(".");
    cal_X += analogRead(joystick_X);
    delay(5);
    cal_Y += analogRead(joystick_Y);
    delay(5);
  }
  X_CENTER = (cal_X/100);
  Y_CENTER = (cal_Y/100);
  Serial.print("\nCorrection X: ");Serial.print(X_CENTER);
  Serial.print("\nCorrection Y: ");Serial.println(Y_CENTER);
  
  Serial.println("\nplace the joystick in the bottom-left corner");
  X_MIN = 0;    //reset the values
  Y_MIN = 0;
  delay(5000);
  Serial.print("calibrating position");
   for (int i = 0; i < 100; i++) {    //take 100 readings
    Serial.print(".");
    X_MIN += analogRead(joystick_X);
    delay(5);
    Y_MIN += analogRead(joystick_Y);
    delay(5);
  }
  X_MIN /= 100;
  Y_MIN /= 100;
  Serial.println();
  Serial.print("X: "); Serial.println(X_MIN);
  Serial.print("Y: "); Serial.println(Y_MIN);

Serial.println("\nplace the joystick in the top-right corner");
  X_MAX = 0;    //reset the values
  Y_MAX = 0;
  delay(5000);
  Serial.print("calibrating position");
   for (int i = 0; i < 100; i++) {    //take 100 readings
    Serial.print(".");
    X_MAX += analogRead(joystick_X);
    delay(5);
    Y_MAX += analogRead(joystick_Y);
    delay(5);
  }
  X_MAX /=  100;
  Y_MAX /=  100;
  Serial.println();
  Serial.print("X: "); Serial.println(X_MAX);
  Serial.print("Y: "); Serial.println(Y_MAX);

  if(X_MAX < X_MIN){
    unsigned long val = X_MAX;
    X_MAX = X_MIN;
    X_MIN = val;
  }
  if(Y_MAX < Y_MIN){
    unsigned long val = Y_MAX;
    Y_MAX = Y_MIN;
    Y_MIN = val;
  }

  Serial.print("\nrange X: ");Serial.print(X_MIN);Serial.print(" - ");Serial.println(X_MAX);
  Serial.print("range Y: ");Serial.print(Y_MIN);Serial.print(" - ");Serial.println(Y_MAX);
    
  Serial.println("\n---calibration done---\n");
}


//some people added this function to the Arduino core, comment this if it's already in the Arduino core
float mapfloat(float x, float in_min, float in_max, float out_min, float out_max)
{
  return (x - in_min) * (out_max - out_min) / (in_max - in_min) + out_min;
}

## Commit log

2026-01-18 Create Button PCB.zip
2026-01-28 Create button pcb.jpeg
2026-01-29 Create Main Frame.stl
    [Main Frame.stl]

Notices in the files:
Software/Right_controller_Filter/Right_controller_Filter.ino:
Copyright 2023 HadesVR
